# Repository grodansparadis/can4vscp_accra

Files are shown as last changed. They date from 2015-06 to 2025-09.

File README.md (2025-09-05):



-----

# The CAN4VSCP Accra general counter module</h1>

This module is part of the [VSCP project](https://www.vscp.org).  It is free to use, modify and sell. The only thing we kindly ask is that improvements and extensions are contributed back to the project (at your will). This to make the project better for everyone. All design files is licensed under the [MIT license](https://en.wikipedia.org/wiki/MIT_License).

The module is documented [here](https://grodansparadis.github.io/can4vscp_accra/#/)

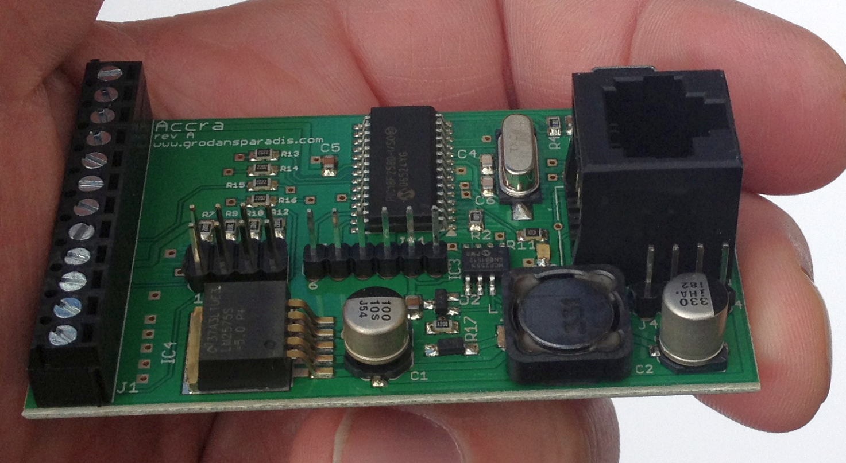
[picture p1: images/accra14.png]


## Abstract

Accra is a general counter module that connects to a CAN4VSCP bus and can count pulses on four channels. The module can be attached to a standard DIN Rail or be mounted directly on a wall.

The module fully adopts to the CAN4VSCP specification and can be powered directly over the bus with a 9-28V DC power source. It has a rich register set for configuration and any information events defined. It also have a decision matrix for easy dynamic event handling.

VSCP CAN modules are designed to work on a VSCP4CAN bus which use ordinary RJ-45 connectors and is powered with 9-30V DC over the same cable. This means there is no need for a separate power cable. All that is needed is a CAT5 or better twisted pair cable. Bus length can be a maximum of 500 meters with drops of maximum 24 meters length (up to a total of 120 meters). As for all VSCP4CAN modules the communication speed is fixed at 125 kbps.

All VSCP modules contains information of there own setup, manual, hardware version, manufacturer etc. You just ask the module for the information you need and you will get it. When they are started up they have a default functionality that often is all that is needed to get a working setup. If the module have something to report it will send you an event and if it is setup to react on a certain type of event it will do it's work when you send event(s) to it. 

---

## Project files

### User manual
  * [User Manual](https://grodansparadis.github.io/can4vscp_accra/#)

### Schematic, PCB, 3D files etc
  * [Schematics reversion A](https://raw.githubusercontent.com/grodansparadis/can4vscp_accra/refs/heads/master/eagle/accra_sch_rev_A.png)
 * Hardware design files is made in [KiCad](https://kicad.org) and can be found in the `kicad` directory. Valid from reversion B of the hardware.
   * Gerber files for PCB production can be found in the `gerber` directory (in the `kicad` folder).
 * Eagle schema and board files for reversion A and B can be found in the `eagle` directory. They are no longer actively updated.

 ### Firmware

 The firmware is developed in [MPLAB X IDE](https://www.microchip.com/mplab/mplab-x-ide) using the [XC8 compiler](https://www.microchip.com/mplab/compilers).

  * Binary release files is available [here](https://github.com/grodansparadis/can4vscp_kelvin_ntc10k/releases)

### MDF - Module Description File(s)
  * [MDF file version: 6 Release date: 2024-04-22](http://www.eurosource.se/accra_1.xml)

### Support
If you need support, please open an issue in the [GitHub repository](https://github.com/grodansparadis/can4vscp_kelvin_ntc10k/issues).

### Buy a ready made modules
You can buy a ready made module from [Grodans Paradis](http://www.grodansparadis.com).

### Project related links
  * [VSCP project](https://www.vscp.org)
  * [VSCP Documentation site](https://docs.vscp.org/)
  * [VSCP Wiki](https://github.com/grodansparadis/vscp/wiki)

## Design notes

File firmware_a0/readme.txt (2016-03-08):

Readme file for the Kelvin SHT11 project. This project is also the base for a VSCP implemention
on a Microchip 18F PIC device.

Version 0.03 2004-12-24

This project ia available in two versions for each processor. One have an "i" at the end meaning that it 
is for the ICD2 debugger.

Non ICD2 projects are built for use with the bootloader. The bootloader occupies space between 0x000 and 0x1ff. 
Vectors are relocated to 0x200. This is managed in the linker scripts. Also the C initialization code has 
been changed to start code at the relocated vector. This also means that the bootloader has to be programmed
into the chip before the working with the project. It also means that the environment must be configured 
*not* to erase the chip before programming it.

If no bootloader is required it is OK to use the standard C startup code, a standard linker description. In this 
case the absolute vector address for the low priority interrup in main.c  must be changed back froo 0x218 to 0x18.

Steps you should go through to adopt this file for your own VSCP project.
=========================================================================

1.) The frequency for your system may be different. This will affect the CAN bit rate settings
which are defined in the biginning of the can18f.c file. Here you also find the filter/mask 
defines if you need to change these.

Timer0 is used as a 1 ms timer for the VSCP functionality. You should adopt the timer reload value 
in the main.h file to your system.

2.) The GUID (Glocal Unique ID) is defined in the beginning of vscp.c This number should be 
different for each piece of equiment you produce. Regard it is as the device serial number. It
can be moved to EEPROM if that is found more convinient. In that case the vscp_rcv_readreg 
procedure in vscp.c also has to be changed.

3.) The device URL is defined in the beginning of the vscp.c file. This is an URL without the
initial "http://" that should point to a XML file that give information about your piece of 
equipment.

4.) The manufacturer id is also defined in the beginning of the vscp.c file. You can use this
id in any way you like.

In addition to this you may use different pins for the INIT button (RC0 today) and the 
status LED (RC1) today. Changes affect the main interrupt vector.

Available builds
================
- kelvin_sht_458i.mcw is for a special 18F485 board *with* ICD2 support.
- kelvin_sht_458.mcw is for 18F485 board *with* bootloader.
- kelvin_sht_258i.mcw is for tke Levin board *with* ICD2 support.
- kelvin_sht_258.mcw is for tke Levin board *with* bootloader.

VSCP (Very Simple Control Protocol) 
http://www.vscp.org

akhe@eurosource.se

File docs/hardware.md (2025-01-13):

## Most current information

You can find the most current information about the Accra module at it's repsitory <https://github.com/grodansparadis/can4vscp_accra> and in the documentation at 
<https://grodansparadis.github.io/can4vscp_accra>. In the repository you can
also find links to the latest firmware, drivers and schematics etc for
its use. You can find links to where you can buy ready made modules here.

## The raw facts

| Parameter | Value |
| --- | --- |
| Current hardware reversion | A |
| Current firmware version | 1.0.0 |
| Supply voltage | \+9 - +28 VDC |
| PCB Size | 42mm x 72mm |
| Power requirements | 0.1W |
| Communication: CAN4VSCP (CAN) | 125 kbps |
| Max frequency channel 0/1 | 25KHz |
| Max frequency channel 2/3 | 10KHz |

## Schematics

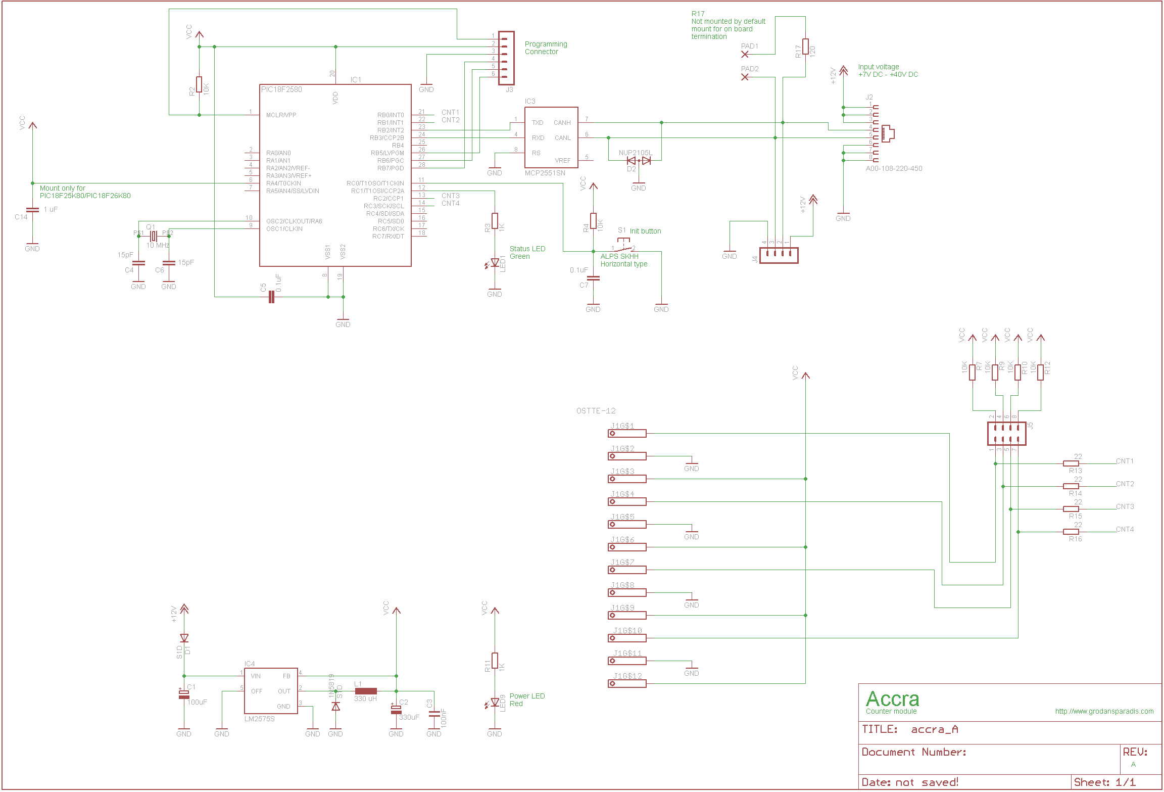
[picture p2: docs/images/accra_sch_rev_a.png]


Schematics: Rev A (click picture to enlarge)

## Board components

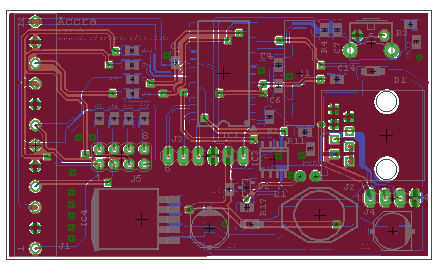
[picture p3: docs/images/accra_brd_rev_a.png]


## Connectors

### Terminal block

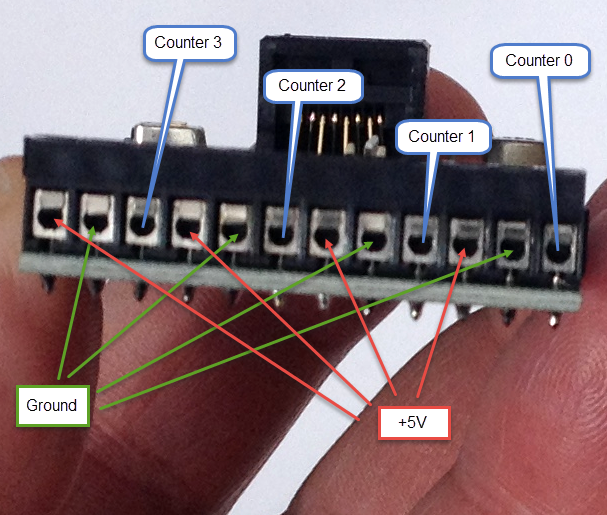
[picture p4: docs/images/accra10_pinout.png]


| Pin | Description |
| --- | --- |
| 1 | Counter 0 input |
| 2 | GND |
| 3 | \+5V |
| 4 | Counter 1 input |
| 5 | GND |
| 6 | \+5V |
| 7 | Counter 2 input |
| 8 | GND |
| 9 | \+5V |
| 10  | Counter 3 input |
| 11  | GND |
| 12  | \+5V |

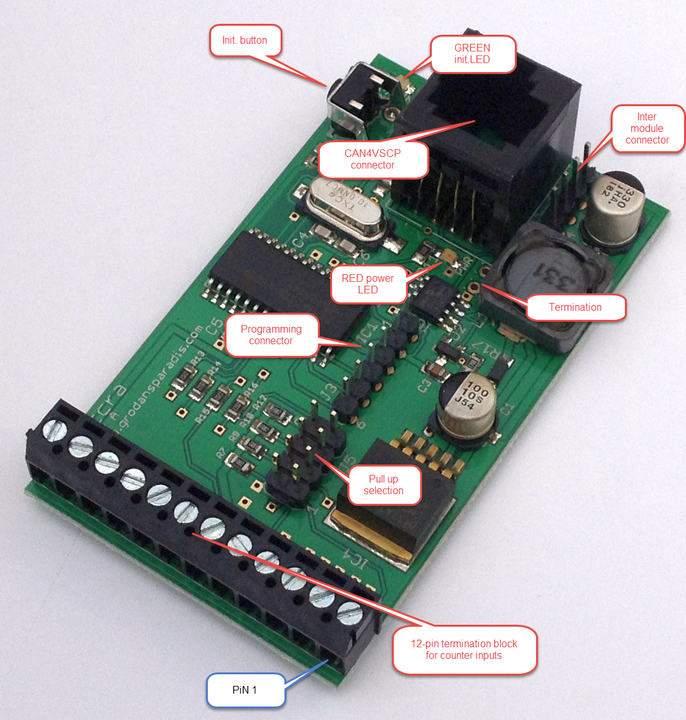
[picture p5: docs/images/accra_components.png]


### Pull up's

| pair | Description |
| ---- | --- |
| 1-2  | Enable 10K pullup to 5V for channel 0 |
| 3-4  | Enable 10K pullup to 5V for channel 1 |
| 5-6  | Enable 10K pullup to 5V for channel 2 |
| 7-0  | Enable 10K pullup to 5V for channel 3 |

### RJ-XX pin-out

The unit is powered over the CAN4VSCP bus. The CAN4VSCP normally uses
CAT5 or better twisted pair cable. You can use other cables if you
which. The important thing is that the CANH and CANL signals uses a
twisted cable. For connectors you can use RJ10, RJ11, RJ12 or the most
common RJ45 connectors.

Recommended connector is RJ-34/RJ-12 or RJ-11 with pin out as in this
table.

| Pin | Use | RJ-11 | RJ-12 | RJ-45 | Patch Cable wire color T568B |
| ----- | --- | ----- | ----- | ----- | --- |
| 1 | \+9-28V DC | | | RJ-45 | Orange/White |
| 2 1 | \+9-28V DC | | RJ-12 | RJ-45 | Orange |
| 3 2 1 | \+9-28V DC | RJ-11 | RJ-12 | RJ-45 | Green/White |
| 4 3 2 | CANH | RJ-11 | RJ-12 | RJ-45 | Blue |
| 5 4 3 | CANL | RJ-11 | RJ-12 | RJ-45 | Blue/White |
| 6 5 4 | GND | RJ-11 | RJ-12 | RJ-45 | Green |
| 7 6 | GND | | RJ-12 | RJ-45 | Brown/White |
| 8 | GND | | | RJ-45 | Brown |

---

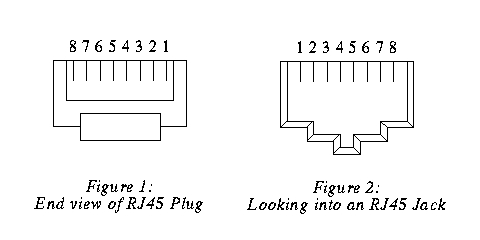
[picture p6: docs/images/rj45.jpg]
RJ-11/12/45 pin-out
 

**RJ-11/12/45 pin-out**

:\!: Always use a pair of twisted wires for CANH/CANL for best noise
immunity. If the EIA/TIA 56B standard is used this condition will be
satisfied. This is good as most Ethernet networks already is wired this
way.

### Inter module connector

The inter module connector can be used to connect modules that are
physically close to each other together in an easy way. Remember that
the minimum length of a connection cable is 30 cm.

| Pin | Description |
| --- | --- |
| 1 | Power from CAN4VSCP bus |
| 2 | CANH |
| 3 | CANL |
| 4 | GND |



### PIC programming Connector

| pin | Description |
| --- | --- |
| 1 | Reset |
| 2 | VCC |
| 3 | GND |
| 4 | PGD (RX of second serial port is here to) |
| 5 | PGC (TX of second serial port is here to) |
| 6 | LWPGM |



### Functionality of the status LED

The LED is used to indicate the status of the module. It will light
steady when the firmware is running and will blink when the module is in
the nickname discovery process.

| LED | Description  |
| --- | --- |
| Steady | No error. Firmware running. |
| Blinking | Module is going through the [nickname discovery process](http://www.vscp.org/docs/vscpspec/doku.php?id=vscp_level_i_specifics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). |

### CAN

CAN4VSCP is a CAN based bus running at 125 kbps with the addition of DC
power. If you are interested in how CAN works you have a pretty good
intro [here](http://www.eeherald.com/section/design-guide/esmod9.html).

CAN is known to be robust and is there for used in vehicles and in the
industry.

[filename](./bottom-copyright.md ':include')

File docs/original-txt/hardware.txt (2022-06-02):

====== Hardware ======

=====  Most current information ===== 
You can find the most current information about the Accra module at \\ [[http://www.grodansparadis.com/accra/accra.html]]. On the site you can also find links to the latest firmware, drivers and schematics etc for its use. 

=====  The raw facts ===== 

^ Parameter ^ Value ^
| Current hardware reversion | A |
| Current firmware version | 1.0.0 |
| Supply voltage | +9 - +28 VDC |
| PCB Size | 42mm x 72mm |
| Power requirements | 0.1W |
| Communication: CAN4VSCP (CAN) | 125 kbps |
| Max frequency channel 0/1 | 25KHz |
| Max frequency channel 2/3 | 10KHz |

===== Schematics ===== 

{{:accra_sch_rev_a.png?700|}}

Schematics: Rev A (click picture to enlarge)

===== Board components ===== 

{{:accra_components.png?700|}}
===== Connectors =====

==== Terminal block ====

{{:accra10_pinout.png?400|}}

^ Pin ^ Description ^ 
| 1 | Counter 0 input | 
| 2 | GND | 
| 3 | +5V | 
| 4 | Counter 1 input | 
| 5 | GND | 
| 6 | +5V | 
| 7 | Counter 2 input | 
| 8 | GND | 
| 9 | +5V | 
| 10 | Counter 3 input | 
| 11 | GND | 
| 12 | +5V | 

==== Pull up's ====

^ pair ^Description ^
| 1-2 | Enable 10K pullup to 5V for channel 0 |
| 3-4 | Enable 10K pullup to 5V for channel 1 |
| 5-6 | Enable 10K pullup to 5V for channel 2 |
| 7-0 | Enable 10K pullup to 5V for channel 3 |

==== RJ-XX pin-out ====

The unit is powered over the CAN4VSCP bus. The CAN4VSCP normally uses CAT5 or better twisted pair cable. You can use other cables if you which. The important thing is that the CANH and CANL signals uses a twisted cable. For connectors you can use RJ10, RJ11, RJ12 or the most common RJ45 connectors.

Recommended connector is RJ-34/RJ-12 or RJ-11 with pin out as in this table.

^ Pin ^ Use ^ RJ-11 ^ RJ-12 ^ RJ-45 ^ Patch Cable wire color T568B ^
| 1 | +9-28V DC	| | | RJ-45 | Orange/White |
| 2 1 | +9-28V DC | | RJ-12 | RJ-45 | Orange |
| 3 2 1	| +9-28V DC | RJ-11 | RJ-12 | RJ-45 | Green/White |
| 4 3 2	| CANH | RJ-11 | RJ-12 | RJ-45 | Blue |
| 5 4 3	| CANL | RJ-11 | RJ-12 | RJ-45 | Blue/White |
| 6 5 4	| GND | RJ-11 | RJ-12 | RJ-45 | Green |
| 7 6 | GND | | RJ-12 | RJ-45 | Brown/White |
| 8 | GND |  |  | RJ-45 | Brown |

{{ :rj45.jpg?300 |RJ-11/12/45 pin-out}}
**RJ-11/12/45 pin-out**

:!: Always use a pair of twisted wires for CANH/CANL for best noise immunity. If the EIA/TIA 56B standard is used this condition will be satisfied. This is good as most Ethernet networks already is wired this way. 

==== Inter module connector ====

The inter module connector can be used to connect modules that are physically close to each other together in an easy way. Remember that the minimum length of a connection cable is 30 cm.

^ Pin ^Description ^
| 1 | Power from CAN4VSCP bus |
| 2 | CANH |
| 3 | CANL |
| 4 | GND |

\\ 

{{ :odessa_inter_module_connector.png?600 |}} 

==== PIC programming Connector ====

^ pin  ^ Description  ^
| 1 | Reset |
| 2 | VCC |
| 3 | GND |
| 4 | PGD (RX of second serial port is here to) |
| 5 | PGC (TX of second serial port is here to) |
| 6 | LWPGM |

\\ 

{{::odessa_programming_connector.png?700|}}

==== Functionality of the status LED ====

The LED is used to indicate the status of the module. It will light steady when the firmware is running and will blink when the module is in the nickname discovery process.

^ LED ^ Description ^
| Steady | No error. Firmware running. |
| Blinking | Module is going through the [[http://www.vscp.org/docs/vscpspec/doku.php?id=vscp_level_i_specifics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|nickname discovery process]]. |

==== CAN ====

CAN4VSCP is a CAN based bus running at 125 kbps with the addition of DC power. If you are interested in how CAN works you have a pretty good intro [[http://www.eeherald.com/section/design-guide/esmod9.html|here]].

CAN is known to be robust and is there for used in vehicles and in the industry.

\\ 
---- 
{{ :grodan_logo.png?100 |}}
\\ 
<html><center></html>
**Paradise of the Frog AB** Brattbergavägen 17 820 50 LOS SWEDEN\\  
**email:** [[info@grodansparadis.com]] **phone:** +46 (0)8 40011835 \\ 
**web:**[[http://www.grodansparadis.com]] \\ 
<html></center></html>

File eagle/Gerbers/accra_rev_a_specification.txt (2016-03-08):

Ake Hedman
Grodans Paradis AB

Date:				2014-06-18
Part Number: 		Accra
Number of cards:	120
Number of layers: 	2 
Material: 			FR4
Final Thickness:	1.6 mm
Final copper:		1/1oz
Surface treatment: 	ENIG
Unit Size:			72 x 42 mm
Panel Size:			154*126 mm
Unit/panel:			6
Solder Mask:		Green
Silk Screen: 		White	
Outline Profile:	CNC Routing + V-cut
X-out Allowed:		1
Stencil needed:		yes
Gerber layer for Stencil: Component Cream (pmc)

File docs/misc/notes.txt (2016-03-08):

Accra notes
===========

http://www.best-microcontroller-projects.com/pic-frequency-counter.html
http://www.best-microcontroller-projects.com/frequency-counter.html
http://www.circuitvalley.com/2011/07/60-mhz-frequency-meter-counter.html

Registers
=========
00	Zone
01	Subzone
02	Control register Counter 0
		Bit 0 - Enable
		Bit 1 - 
		Bit 2 - 
		Bit 3 - 
		Bit 4 - 
		Bit 5 - 
		Bit 6 -
		Bit 7 -  		
03	Control register Counter 1
04	Control register Counter 2
05	Control register Counter 3
06	Control register Counter 4

07	Counter 0 MSB
08	Counter 0 
09	Counter 0 
0A	Counter 0 LSB

0B	Counter 1 MSB
0C	Counter 1 
0D	Counter 1 
0E	Counter 1 LSB

0F	Counter 2 MSB
10	Counter 2 
11	Counter 2 
12	Counter 2 LSB

13	Counter 3 MSB
14	Counter 3 
15	Counter 3 
16	Counter 3 LSB

17	Counter 4 MSB
18	Counter 4 
19	Counter 4 
1A	Counter 4 LSB

1B  Delta channel 0 MSB
1C  Delta channel 0 LSB

1B  Frequency channel 0 MSB
1C  Frequency channel 0 
1D  Frequency channel 0 
1E  Frequency channel 0 LSB

1B  Frequency channel 1 MSB
1C  Frequency channel 1 
1D  Frequency channel 1 
1E  Frequency channel 1 LSB

1B  Frequency channel 2 MSB
1C  Frequency channel 2 
1D  Frequency channel 2 
1E  Frequency channel 2 LSB

1B  Frequency channel 3 MSB
1C  Frequency channel 3 
1D  Frequency channel 3 
1E  Frequency channel 3 LSB

1B  Frequency channel 4 MSB
1C  Frequency channel 4 
1D  Frequency channel 4 
1E  Frequency channel 4 LSB

// y = k*x + m
1F	Linear equation k constant double for channel 0 MSB
20	Linear equation k constant double for channel 0 
21	Linear equation k constant double for channel 0 
22	Linear equation k constant double for channel 0 MSB

23	Linear equation k constant double for channel 1 MSB
24	Linear equation k constant double for channel 1 
25	Linear equation k constant double for channel 1 
26	Linear equation k constant double for channel 1 MSB

27	Linear equation k constant double for channel 2 MSB
28	Linear equation k constant double for channel 2 
29	Linear equation k constant double for channel 2 
2A	Linear equation k constant double for channel 2 MSB

2B	Linear equation k constant double for channel 3 MSB
2C	Linear equation k constant double for channel 3 
2D	Linear equation k constant double for channel 3 
2E	Linear equation k constant double for channel 3 MSB

2F	Linear equation k constant double for channel 4 MSB
30	Linear equation k constant double for channel 4 
31	Linear equation k constant double for channel 4 
32	Linear equation k constant double for channel 4 MSB

33	Linear equation m constant double for channel 0 MSB
34	Linear equation m constant double for channel 0 
35	Linear equation m constant double for channel 0 
36	Linear equation m constant double for channel 0 MSB

37	Linear equation m constant double for channel 1 MSB
38	Linear equation m constant double for channel 1 
39	Linear equation m constant double for channel 1 
3A	Linear equation m constant double for channel 1 MSB

3B	Linear equation m constant double for channel 2 MSB
3C	Linear equation m constant double for channel 2 
3D	Linear equation m constant double for channel 2 
3E	Linear equation m constant double for channel 2 MSB

3F	Linear equation m constant double for channel 3 MSB
40	Linear equation m constant double for channel 3 
41	Linear equation m constant double for channel 3 
42	Linear equation m constant double for channel 3 MSB

43	Linear equation m constant double for channel 4 MSB
44	Linear equation m constant double for channel 4 
45	Linear equation m constant double for channel 4 
46	Linear equation m constant double for channel 4 MSB

1:00	Control for measurement event sensor 0
		Bit 0 - Event selection
		Bit 1 - Event selection
		Bit 2 - Event selection
		Bit 3 - 
		Bit 4 - 
		Bit 5 - 
		Bit 6 -
		Bit 7 - 
		
1:01	Control for measurement event sensor 1		
1:02	Control for measurement event sensor 2
1:03	Control for measurement event sensor 3
1:04	Control for measurement event sensor 4

1:05  	Zone for measurement event sensor 0
1:06  	Zone for measurement event sensor 1
1:07  	Zone for measurement event sensor 2
1:08  	Zone for measurement event sensor 3
1:09  	Zone for measurement event sensor 4

1:0A  	Subzone for measurement event sensor 0
1:0B  	Subzone for measurement event sensor 1
1:0C  	Subzone for measurement event sensor 2
1:0D  	Subzone for measurement event sensor 3
1:0E  	Subzone for measurement event sensor 4

1:0F  	Event class for measurement event sensor 0 MSB
1:10  	Event class for measurement event sensor 0 LSB

1:11  	Event class for measurement event sensor 0 MSB
1:12  	Event class for measurement event sensor 0 LSB

1:13  	Event class for measurement event sensor 0 MSB
1:14  	Event class for measurement event sensor 0 LSB

1:15  	Event class for measurement event sensor 0 MSB
1:16  	Event class for measurement event sensor 0 LSB

1:17 	Event class for measurement event sensor 0 MSB
1:18  	Event class for measurement event sensor 0 LSB

1:19  	Event type for measurement event sensor 0 MSB
1:1A  	Event type for measurement event sensor 0 LSB

1:1B	Data coding for measurement event sensor 0
1:1C	Data coding for measurement event sensor 1
1:1D	Data coding for measurement event sensor 2
1:1E	Data coding for measurement event sensor 3
1:1F	Data coding for measurement event sensor 4

Actions
=======
0	NOOP
1	Send state. (for sync)

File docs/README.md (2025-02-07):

## Manual for the Accra module

**Document version:** ${/var/document-version} - ${/var/creation-time}
[HISTORY](./history.md)

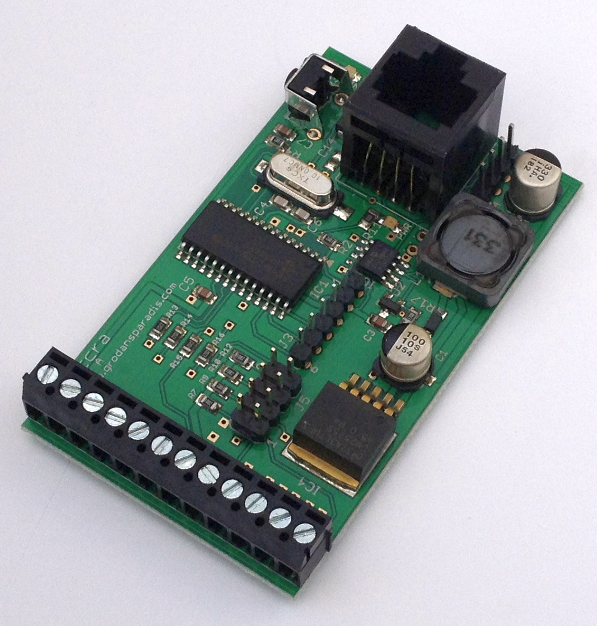
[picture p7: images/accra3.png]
Accra


Accra is a module that have four counter channels that each can count
pulses and measure frequency. Each channel can have alarms set for going
over a counter level or when counting down to zero and for a frequency
that goes outside of a specified frequency window.

It has a built-in linear calculation algorithm that can translate pulse
to real world measurement units. This can for example be used for
utility meter measurements and gives the correct measurement value sent
out on the VSCP bus.

The module comes with a GUID and is programmed with a bootloader and
VSCP module functionality that works right out of the box.

* [Repository for the module](https://github.com/grodansparadis/can4vscp_accra)
  * This manual is available [here](https://grodansparadis.github.io/can4vscp_accra/)
  * Latest schema for the module is available [here](https://github.com/grodansparadis/can4vscp_accra/tree/master/eagle)
  * Latest firmware for the module is available [here](https://github.com/grodansparadis/can4vscp_accra/tree/master/firmware)
  * [MDF for the module](https://github.com/grodansparadis/can4vscp_accra/tree/master/mdf)

## VSCP

VSCP logo

VSCP is a free and open automation protocol for IoT and m2m devices. Visit [the VSCP site](https://www.vscp.org) for more information.

**VSCP is free.** Placed in the **public domain**. Free to use. Free to change. Free to do whatever you want to do with it. VSCP is not owned by anyone. VSCP will stay free and gratis forever.

The specification for the VSCP protocol is [here](https://docs.vscp.org) 

VSCP documentation for various parts can be found [here](https://docs.vscp.org/).

If you use VSCP please consider contributing resources or time to the project ([https://vscp.org/support.php](https://vscp.org/support.php)).

## Buy a module

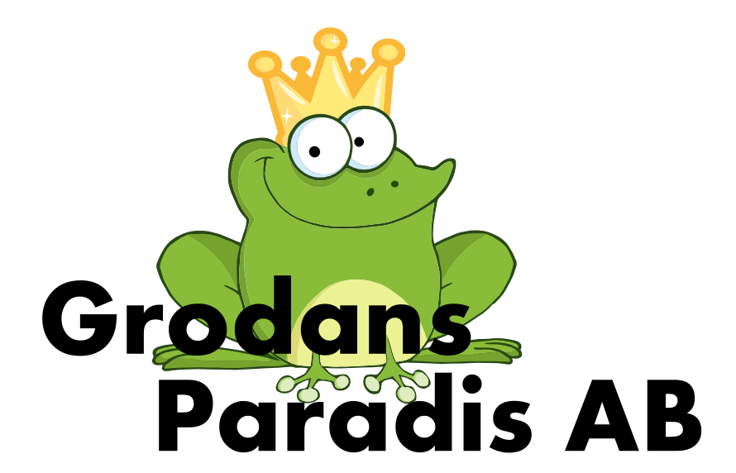
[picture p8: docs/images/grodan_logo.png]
Grodans PAradis AB


Ready made modules can be bought from [Grodans Paradis AB](https://www.grodansparadis.com).

## Document license

This document is licensed under [Creative Commons BY 4.0](https://creativecommons.org/licenses/by/4.0/) and can be freely copied, redistributed, remixed, transformed, built upon as long as you give credits to the author.

[filename](./bottom-copyright.md ':include')

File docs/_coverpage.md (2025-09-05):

VSCP logo

# Manual for the Accra module

Scroll down to view docs.

[Homepage](https://www.vscp.org)
[Docs](https://www.vscp.org/#documentation)
[Downloads](https://www.vscp.org/#download)
[Get Started](./README)

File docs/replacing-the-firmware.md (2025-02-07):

New firmware is released from time to time for all our modules. We
expect this to be true also for the module as it is an active
project. The process of updating the firmware of the module is a simple
one. Just follow the steps outlined in the [VSCP Works
documentation](https://grodansparadis.github.io/vscp-works-qt/#/bootload_window).

## Where is the firmware?

Firmware is available in the Github repository
<https://github.com/grodansparadis/can4vscp_accra/releases> and the [MDF of the module](https://github.com/grodansparadis/can4vscp_accra/tree/master/mdf) contains a list of available firmware files and a pointer to there location. This file is loaded by the firmware updating software of VSCP Works+ and you can select the file you need from there.

### Device firmware code
The standard registers of a module contains a register that holds the firmware code for the module. This is a 16-bit value that can be read by the VSCP firmware update software. The value is a code for the specific hardware the board uses. Typically hardware has been changed and processors have been updated to later versions as time goes. The VSCP firmware update software can use this code to find the correct firmware for the module. It is **VERY** important that the correct firmware is used for the module. If the wrong firmware is used the module will not work as expected and may even be damaged. So make sure this code is the same as the code in the firmware file you use.

Older firmware files may not have this code in the standard registers as it is a pretty late addition to the standard. In that case you should use the latest firmware file for the module for the type of processor you have.

## Where is the source for the firmware?

You can find the latest source for the firmware
[here](https://github.com/grodansparadis/can4vscp_frankfurt_rs232).

## Replacing/updating the bootloader on the module

If you need to update the bootloader on this module you can find firmware files for it [here](https://github.com/grodansparadis/vscp-pic1-bootloader/releases). Select the hex files for your board and use the bootloader application to update the bootloader. When the bootloader is loaded you can use [VSCP Works+](https://grodansparadis.github.io/vscp-works-qt/#/bootload_window) to update the application firmware of the module.

You will need a PICkit3 or similar programmer to update the bootloader.

[filename](./bottom-copyright.md ':include')

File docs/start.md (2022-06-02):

# Accra - General counter module

**Document reversion**: 1.0.0 2015-07-07

Copyright © 2000-2020 Åke Hedman, [Grodans Paradis
AB](http://www.grodansparadis.com),
\<[akhe@grodansparadis.com](akhe@grodansparadis.com)\>

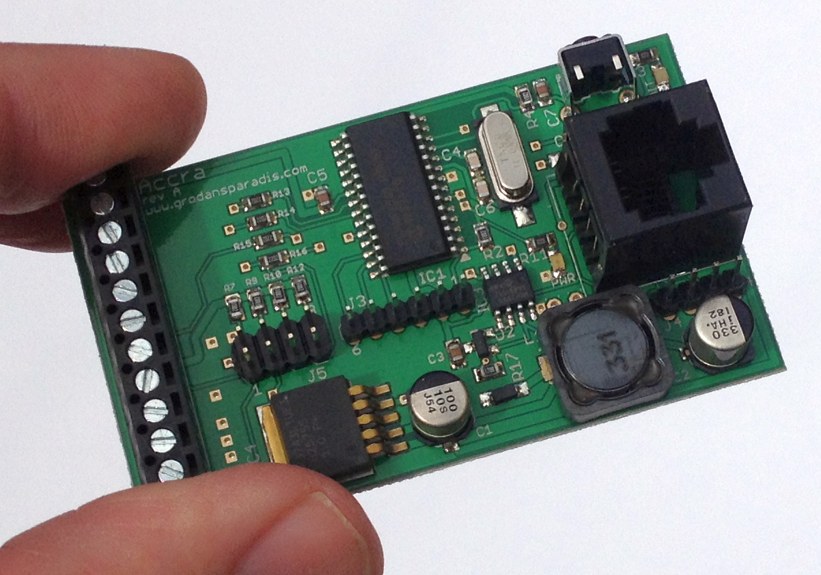
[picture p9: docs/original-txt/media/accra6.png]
Accra


This documentation is for the [Accra
module](http://www.grodansparadis.com/accra/accra.html). The module is
available for international purchase from the
[FrogShop](http://www.frogshop.se).

  - [Introduction](Introduction)
  - [Getting Started](Getting%20Started)
  - [Hardware](Hardware)
  - [CAN4VSCP cabling](CAN4VSCP%20cabling)
  - [Updating the firmware](Replacing%20the%20firmware)
  - [Registers](registers)
  - [Abstractions](Abstractions)
  - [Alarms](Alarms)
  - [Decision Matrix](decisionmatrix)
  - [Events](Events)
  - [Recipes](Recipes)
  - [faq](faq)

//**Disclaimer:** © 2011-2015 Grodans Paradis AB. All rights reserved.
Grodans Paradis AB®, logo and combinations thereof, are registered
trademarks of Grodans Paradis AB. Other terms and product names may be
trademarks of others. The information in this document is provided in
connection with Grodans Paradis AB products. No license, express or
implied or otherwise, to any intellectual property right is granted by
this document or in connection with the sale of Grodans Paradis AB
products. Neither the whole nor any part of the information contained in
or the product described in this document may be adapted or reproduced
in any material from except with the prior written permission of the
copyright holder. The product described in this document is subject to
continuous development and improvements. All particulars of the product
and its use contained in this document are given by Grodans Paradis AB
in good faith. However all warranties implied or expressed including but
not limited to implied warranties of merchantability or fitness for
purpose are excluded. This document is intended only to assist the
reader in the use of the product. Grodans Paradis AB. shall not be
liable for any loss or damage arising from the use of any information in
this document or any error or omission in such information or any
incorrect use of the product. //

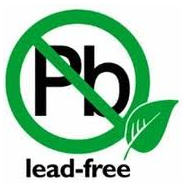
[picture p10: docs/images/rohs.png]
 All boards produced by Grodans Paradis AB are ROHS
compliant.

\----   
<center> **Grodans Paradis AB** Brattbergavägen 17, 827 70 LOS SWEDEN  
**email:** [info@grodansparadis.com](info@grodansparadis.com) **phone:**
+46 (0)8 40011835  
**web:**<https://www.grodansparadis.com>  
</center>

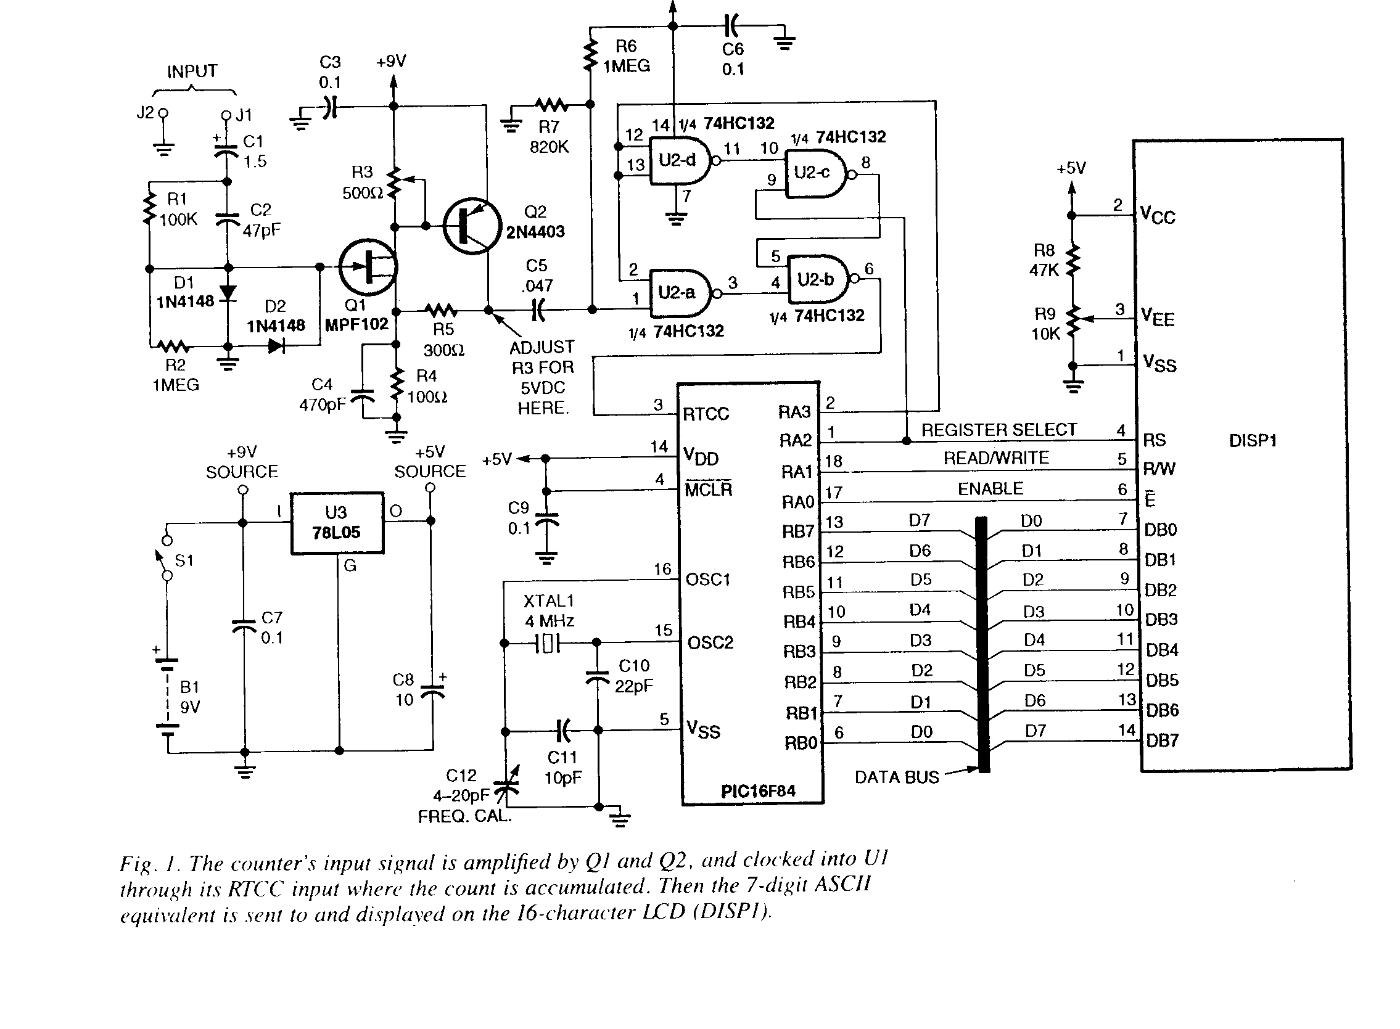
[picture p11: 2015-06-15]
docs/misc/weedfreq.gif

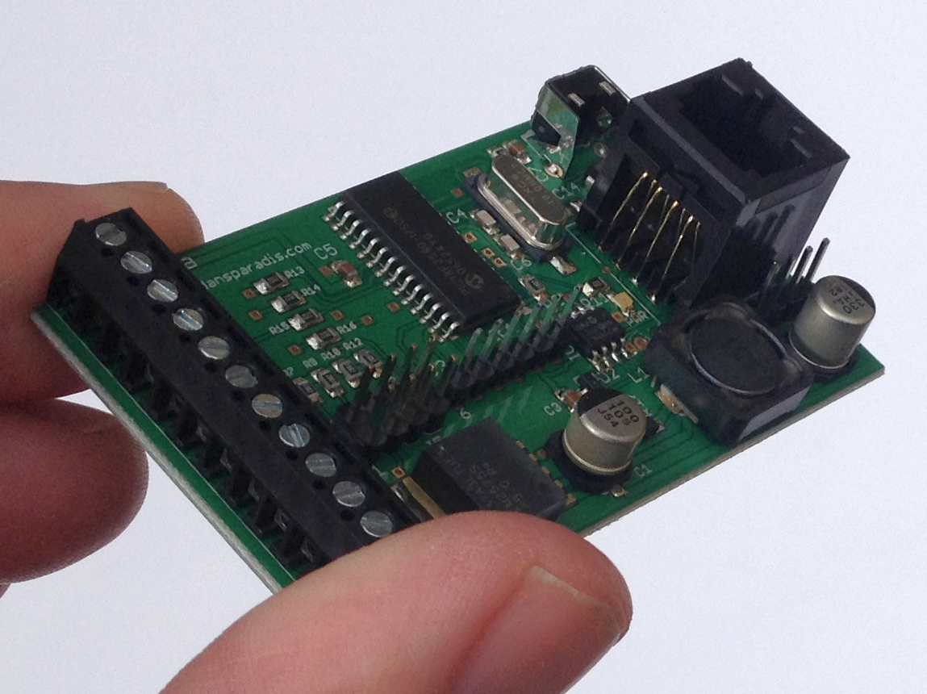
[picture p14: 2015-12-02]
docs/images/accra7.png

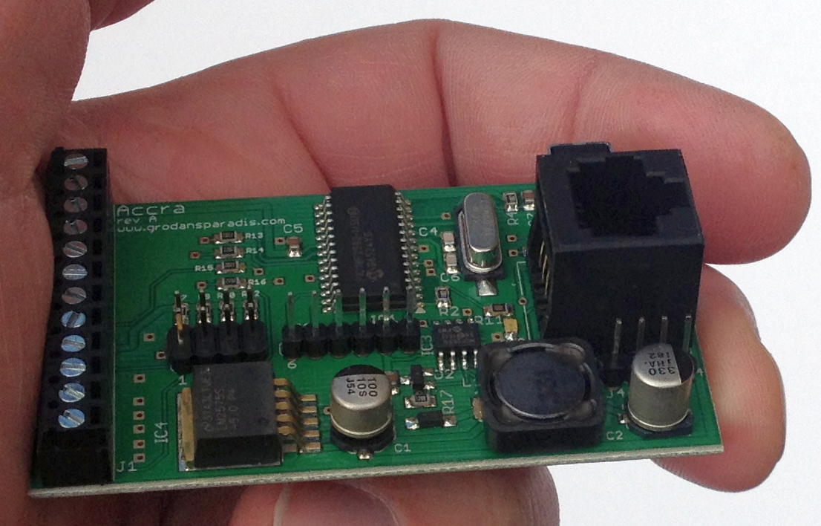
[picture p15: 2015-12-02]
docs/original-txt/media/accra15.png

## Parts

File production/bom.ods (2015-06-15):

Count | Description | Part id | Supplier 1 | Partnumber 1 | Price 1 | Price 1000
1 | Brytare ALPS SKHH Horizontal | S1 | Elfa | 35-677-65 | SEK 2,89 | SEK 1,49
1 | Stiftlist 2.54 6-pin | JP1,JP4 | Digikey | SAM1035-50-ND | USD 2.04 | USD 1.01
1 | Induktance 330 uH, 1A, DO3316P | L1 | Digikey | 553-1514-1-ND | USD 1.28 | USD 1.05
1 | Crystal, SMD, 10 Mhz | Q1 | Digikey | 887-1050-1-ND | USD 0.53 | USD 0.26
1 | LED SMD yellow | LED1
2 | Capacitance 0.1uF 0805 | C3,C5 | Digikey | 311-1361-2-ND | USD 24/4000
1 | Resistance 1K 0805 | R3
1 | Capacitance 100uF | C1
1 | Capacitance 330uF | C2
1 | LM2575S | IC4 | Digikey | LM2575S-3.3/NOPB-ND | USD 2.97 | USD 1.48
1 | MCP2551 SOIC | IC3 | Digikey | MCP2551-I/SN-ND | USD 1.12 | USD 0.78
1 | Diod NUP2105L | D2 | Digikey | NUP2105LT1GOSCT-ND | USD 0.50 | USD 0.17
1 | Microprocessor PIC18F2580 | IC1 | Microchip direct | PIC18F2580-I/SO-ND | USD 5.51 | USD 5.24
1 | ULN2003AD | IC2 | Digikey | 296-1368-1-ND | USD 0.68 | USD 0.23
2 | Resistance 10K 0805 | R2,R4
2 | Capacitance 15pF 0805 | C4,C6 | Digikey | 709-1170-2-ND | USD28.80
2 | Diode 1N5819 SOD123 | D1 | Digikey | 1N5819HW-FDICT-ND | USD 0.48 | USD 0.10
1 | PCB |  | Pcbcart |  | USD 2.05 | USD 1.29
1 | Terminating block 10-pol |  | Digikey | ED2737-ND | USD 1.46 | USD 0.87
1 | RJ-45 connector | J2 | Digikey | 151-1099-ND | USD 0.70 | USD 0.49

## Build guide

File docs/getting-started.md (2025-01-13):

You need

  * RJ-45 patch cables or similar.
  * A stable +9V - +28V DC power source.
  * A host computer with a serial or USB interface.

The Accra module is powered from the CAN4VSCP bus. [This
article](https://github.com/grodansparadis/vscp/wiki/Connecting-CAN4VSCP-devices-together)
have information on how the bus is powered and set up. Follow it for a
reliable setup. Don't forget the 120 ohm terminators at each end of the
bus. <span class="underline">They are important\!</span> You can
activate the on board terminator on the Accra module if it is located at
one end of your bus.

When you power the module by inserting the RJ-45 cable the red LED on
the board should light up to indicate it is powered. This is just a
power indicator LED. When you power the board for the first time the
green led starts to blink to indicate that the module search for a
nickname. During normal operation this LED should light steady.

Remember that there need to be <span class="underline">at least
two</span> CAN4VSCP (or other CAN device set to 125kbps) devices (one
additional) if you have the [Frankfurt
RS-232](https://grodansparadis.github.io/can4vscp-frankfurt-rs232)
or some other bus interface. A single device can't talk by
itself on a bus. It's an error.

[filename](./bottom-copyright.md ':include')

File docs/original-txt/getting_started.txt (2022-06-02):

====== Getting started ======
 
You need

  * RJ-45 patch cables or similar.
  * A stable +9V - +28V DC power source.
  * A host computer with a serial or USB interface.

The Accra module is powered from the CAN4VSCP bus. [[http://www.grodansparadis.com/wiki/doku.php?id=connecting_can4vscp_devices_together|This article]] have information on how the bus is powered and set up. Follow it for a reliable setup. Don't forget the 120 ohm terminators at each end of the bus. __They are important!__  You can activate the on board terminator on the Accra module if it is located at one end of your bus.

When you power the module by inserting the RJ-45 cable the red LED on the board should light up to indicate it is powered. This is just a power indicator LED. When you power the board for the first time the green led starts to blink to indicate that the module search for a nickname. During normal operation this LED should light steady. 

Remember that there need to be __at least two__ CAN4VSCP (or other CAN device set to 125kbps) devices (one additional if you have the [[http://www.grodansparadis.com/frankfurt/rs232/frankfurt-rs232.html|Frankfurt RS-232]]) on the bus to be able to communicate. A single device can't talk by itself on a bus. It's an error.

\\ 
---- 
{{ :grodan_logo.png?100 |}}
\\ 
<html><center></html>
**Paradise of the Frog AB** Brattbergavägen 17 820 50 LOS SWEDEN\\  
**email:** [[info@grodansparadis.com]] **phone:** +46 (0)8 40011835 \\ 
**web:**[[http://www.grodansparadis.com]] \\ 
<html></center></html>

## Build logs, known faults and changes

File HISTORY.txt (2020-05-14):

Accra counter module
====================

2020-05-08 AKHE - Version is 1.0.4   Firmware 1.6.3
2020-05-14 AKHE - Fixed bug that cause init to be performed on all
                  cold starts. Fixed seconds timer.
2020-05-08 AKHE - Version is 1.0.3   firmware 1.6.3
2020-05-08 AKHE - Boot button time increased to > 2500 ms
2016-04-19 AKHE - RA4 set to input to prevent collision with VCAP circuits in 
                  PIC18F2580. Brown out raised to maximum (3V & 4.6V). Valable 
		  input from Anders Forsgren, AJE Electronics AB. 
2016-04-11 AKHE - vscp_getMatrixInfo nw use the pointer supplied by the framework.
2016-04-04 AKHE - Changed value of C14 to 10uF
2016-03-23 AKHE - Version 1.0.2-------------------------------------------------
2016-03-23 AKHE - Adopted for VSCP frimware 1.6.1
2016-03-23 AKHE - Version 1.0.1-------------------------------------------------
2016-03-23 AKHE - Adopted for VSCP firmware 1.6.0
2016-03-23 AKHE - Fixed bug in control byte write.
2016-03-08 AKHE - Adopted to 1.6 firmware. Adopted for PIC18F26K80.
2015-11-15 AKHE - Started development

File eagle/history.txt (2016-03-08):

Accra
=====

2014-06-19 - AKHE Fixed dimensions.
2014-06-18 - AKHE Job sent away.
2014-06-18 - AKHE Changed width on power wires.
2014-06-01 - AKHE Tested with Silvercircuits dru.

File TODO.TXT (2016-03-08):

Accra counter module
====================

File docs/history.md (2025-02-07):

# Change Log for Accra

Change log for the module is at
[here](https://github.com/grodansparadis/can4vscp_accra/blob/master/HISTORY.txt)

| Date | By | Description |
| ---- | -- | ---  |
| 250113 | akhe | Fixed some links |
| 220602 | akhe | Transferred to Markdown format |

[filename](./bottom-copyright.md ':include')

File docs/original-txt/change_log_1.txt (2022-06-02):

====== Change Log for Accra ======

Change log is [[https://github.com/grodansparadis/can4vscp_accra/blob/master/HISTORY.txt|here]]

\\ 
---- 
{{ :grodan_logo.png?100 |}}
\\ 
<html><center></html>
**Paradise of the Frog AB** Brattbergavägen 17 820 50 LOS SWEDEN\\  
**email:** [[info@grodansparadis.com]] **phone:** +46 (0)8 40011835 \\ 
**web:**[[http://www.grodansparadis.com]] \\ 
<html></center></html>

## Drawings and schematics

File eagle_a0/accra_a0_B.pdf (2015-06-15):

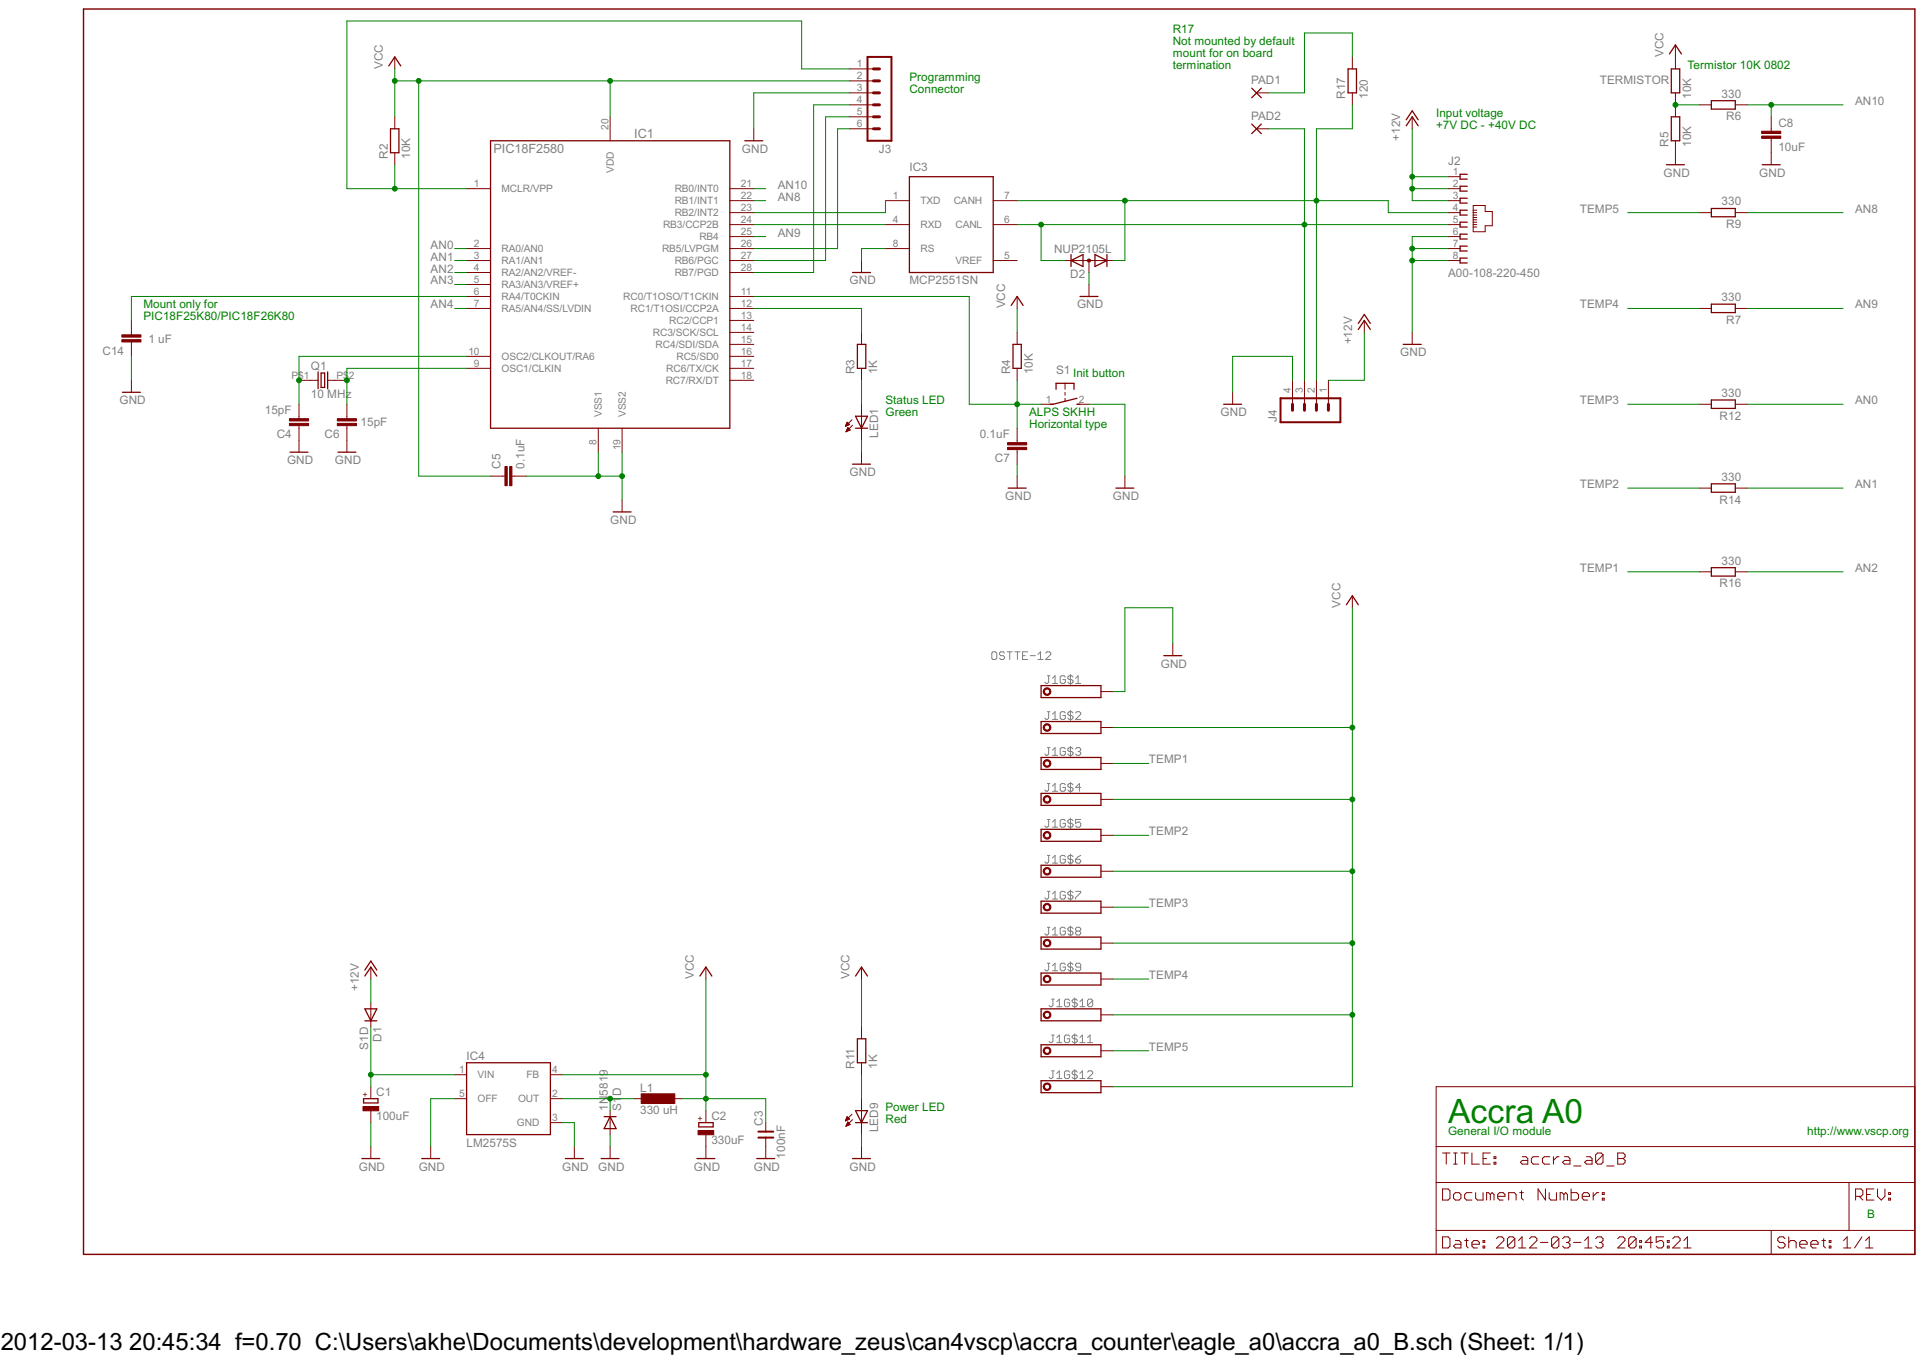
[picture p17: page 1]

termination R17
Not mounted by default mount for on board

Input voltage +7V DC - +40V DC

Init button Status LED

2012-03-13 20:45:34 f=0.70 C:\Users\akhe\Documents\development\hardware_zeus\can4vscp\accra_counter\eagle_a0\accra_a0_B.sch (Sheet: 1/1)

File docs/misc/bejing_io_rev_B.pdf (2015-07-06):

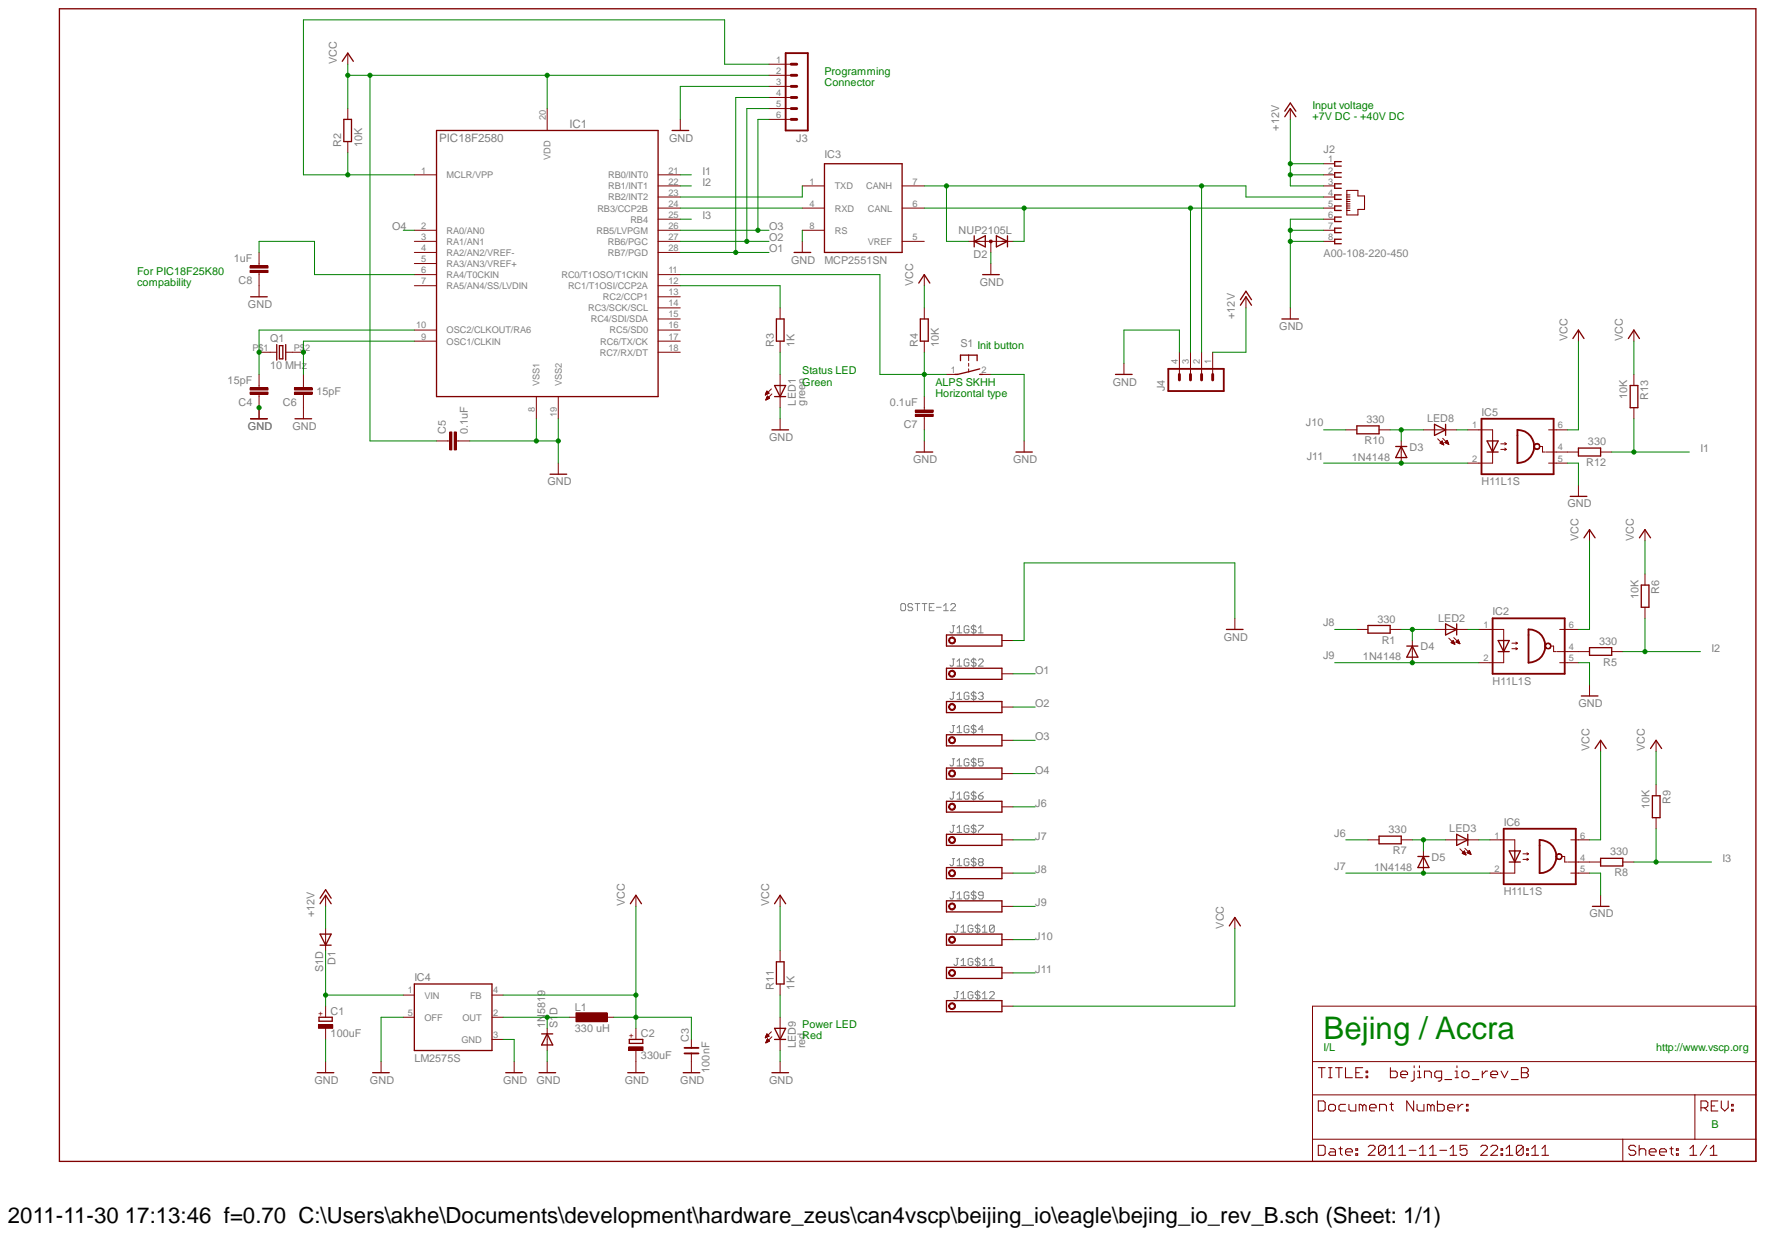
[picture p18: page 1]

2011-11-30 17:13:46 f=0.70 C:\Users\akhe\Documents\development\hardware_zeus\can4vscp\beijing_io\eagle\bejing_io_rev_B.sch (Sheet: 1/1)

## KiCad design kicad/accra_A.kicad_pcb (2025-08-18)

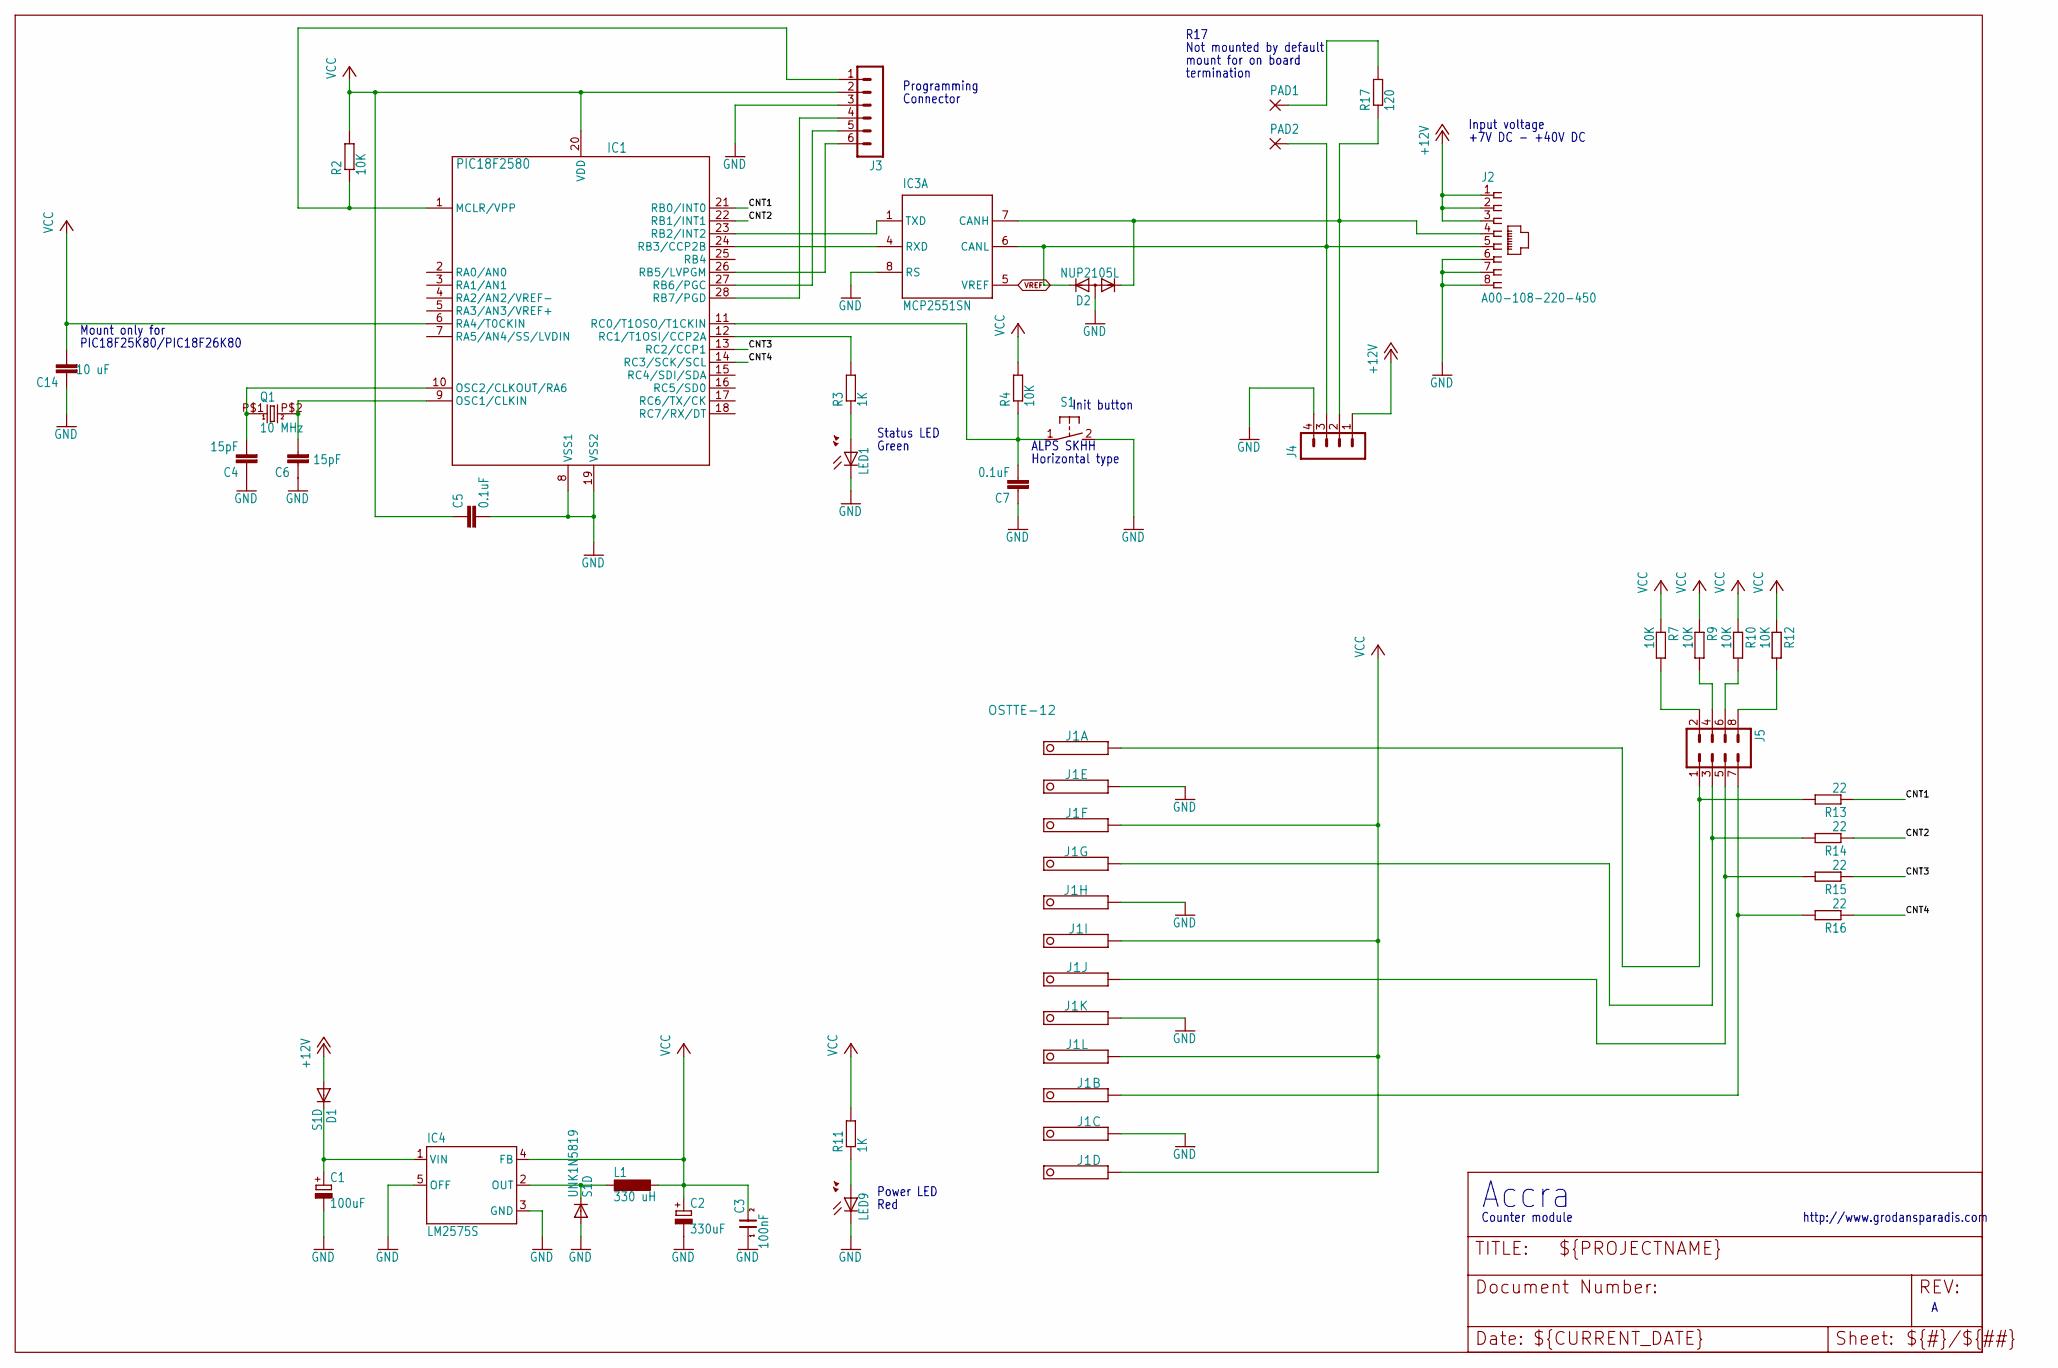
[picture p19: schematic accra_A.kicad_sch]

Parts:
C1: 100uF; PANASONIC_D
C2: 330uF; PANASONIC_D
C3: 100nF; 0805
C4, C6: 15pF; C0805
C5, C7: 0.1uF; C0805
C14: 10 uF; C0805
D1: S1D; SOD123
D2: NUP2105L; SOT23
IC1: PIC18F2580; SO28
IC3: MCP2551SN; SO-08
IC4: LM2575S; TO263-5
J1: OSTTE-12; PINHEAD-12
J2: A00-108-220-450; RJ-45
J3: MA06-1
J4: MA04-1
J5: MA04-2
L1: 330 uH; DO3316P
LED1, LED9: LEDCHIP-LED0805; CHIP-LED0805
PAD1, PAD2: 1,6/0,8; 1,6_0,8
Q1: 10 MHz; 9C
R2, R4, R7, R9, R10, R12: 10K; R0805
R3, R11: 1K; R0805
R13, R14, R15, R16: 22; R0805
R17: 120; R0805
S1: 31-XX; B3F-31XX
UNK1N5819: S1D; SOD123

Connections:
+12V: D1.A, J2.1, J2.2, J2.3, J4.1
CANL: D2.2 (K2), IC3.6 (CANL), J2.5, J4.3, PAD2.1
CNT1: IC1.21 (RB0/INT0), R13.1
CNT2: IC1.22 (RB1/INT1), R14.1
CNT3: IC1.13 (RC2/CCP1), R15.1
CNT4: IC1.14 (RC3/SCK/SCL), R16.1
GND: C1.-, C2.-, C3.1, C4.1, C5.2, C6.1, C7.1, C14.1, D2.3 (A), IC1.8 (VSS1), IC1.19 (VSS2), IC3.2 (VSS), IC3.8 (RS), IC4.3 (GND), IC4.5 (OFF), J1.2, J1.5, J1.8, J1.11, J2.6, J2.7, J2.8, J3.3, J4.4, LED1.C, LED9.C, S1.2 (S), UNK1N5819.A
unnamed: IC4.2 (OUT), L1.1, UNK1N5819.C
unnamed: C4.2, IC1.10 (OSC2/CLKOUT/RA6), Q1.P$1 (1)
unnamed: C1.+, D1.C, IC4.1 (VIN)
unnamed: IC1.12 (RC1/T1OSI/CCP2A), R3.2
unnamed: LED1.A, R3.1
unnamed: C7.2, IC1.11 (RC0/T1OSO/T1CKIN), R4.1, S1.1
unnamed: C6.2, IC1.9 (OSC1/CLKIN), Q1.P$2 (2)
unnamed: J1.4, J5.3, R14.2
unnamed: J1.7, J5.5, R15.2
unnamed: PAD1.1, R17.2
unnamed: IC1.1 (MCLR/VPP), J3.1, R2.1
unnamed: IC1.28 (RB7/PGD), J3.4
unnamed: IC1.27 (RB6/PGC), J3.5
unnamed: IC1.26 (RB5/LVPGM), J3.6
unnamed: J1.10, J5.7, R16.2
unnamed: J5.2, R7.2
unnamed: LED9.A, R11.1
unnamed: D2.1 (K1), IC3.7 (CANH), J2.4, J4.2, R17.1
unnamed: J5.4, R9.2
unnamed: J5.6, R10.2
unnamed: J5.8, R12.2
unnamed: J1.1, J5.1, R13.2
RXCAN: IC1.24 (RB3/CCP2B), IC3.4 (RXD)
TXCAN: IC1.23 (RB2/INT2), IC3.1 (TXD)
VCC: C2.+, C3.2, C5.1, C14.2, IC1.6 (RA4/T0CKIN), IC1.20 (VDD), IC3.3 (VDD), IC4.4 (FB), J1.3, J1.6, J1.9, J1.12, J3.2, L1.2, R2.2, R4.2, R7.1, R9.1, R10.1, R11.2, R12.1
VREF: IC3.5 (VREF)

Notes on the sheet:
Connector
PIC18F25K80/PIC18F26K80
Input voltage
Programming
Init button
Power LED
termination
http://www.grodansparadis.com
+7V DC - +40V DC
Red
Status LED
Green
Counter module
Mount only for
mount for on board
ALPS SKHH
Horizontal type
Accra
Not mounted by default
R17

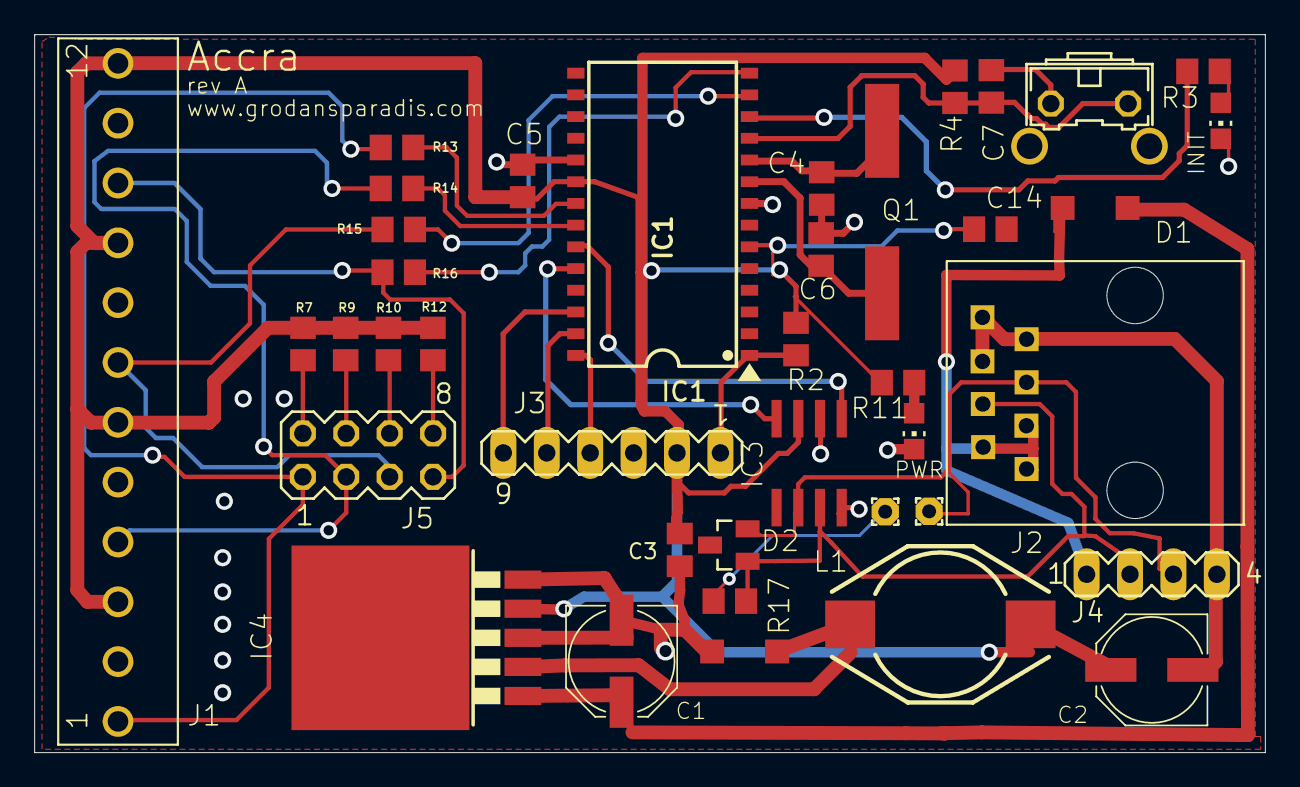
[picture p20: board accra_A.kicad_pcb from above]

Board: 6 copper layers, 72.0 x 42.0 mm, 39 parts (0 on the bottom side), 32 nets.

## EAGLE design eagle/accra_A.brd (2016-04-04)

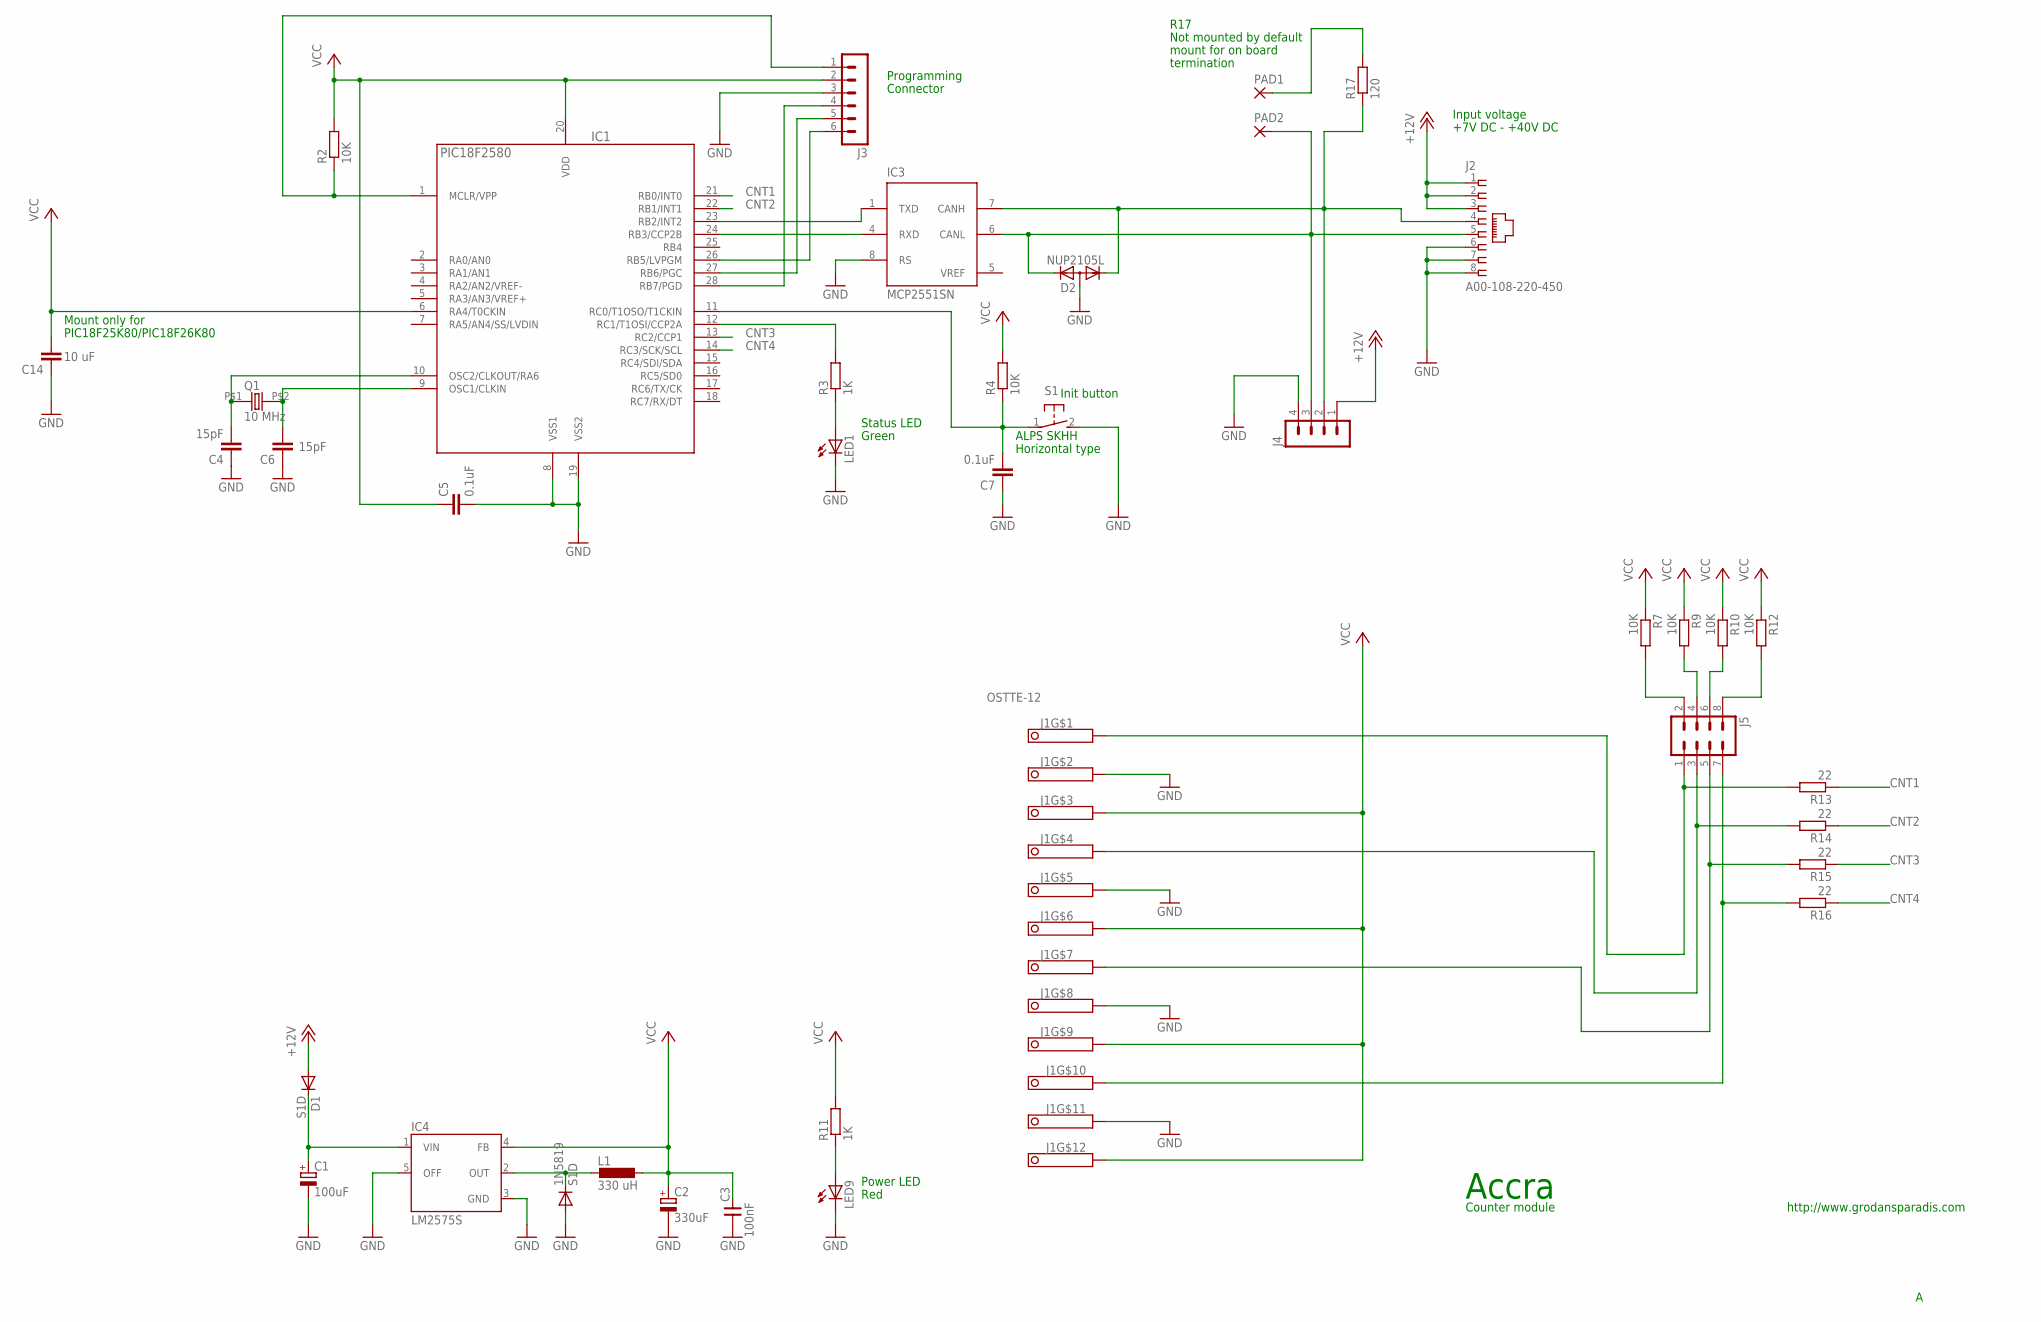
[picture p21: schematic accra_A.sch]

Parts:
1N5819: S1D; SOD123
C1: 100uF; PANASONIC_D
C2: 330uF; PANASONIC_D
C3: 100nF; 0805
C4, C6: 15pF; C0805
C5, C7: 0.1uF; C0805
C14: 10 uF; C0805
D1: S1D; SOD123
D2: NUP2105L; SOT23
IC1: PIC18F2580; SO28
IC3: MCP2551SN; SO-08
IC4: LM2575S; TO263-5
J1: OSTTE-12; PINHEAD-12
J2: A00-108-220-450; RJ-45
J3: MA06-1
J4: MA04-1
J5: MA04-2
L1: 330 uH; DO3316P
LED1, LED9: LEDCHIP-LED0805; CHIP-LED0805
PAD1, PAD2: 1,6/0,8
Q1: 10 MHz; 9C
R2, R4, R7, R9, R10, R12: 10K; R0805
R3, R11: 1K; R0805
R13, R14, R15, R16: 22; R0805
R17: 120; R0805
S1: 31-XX; B3F-31XX

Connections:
+12V: D1.A, J2.1, J2.2, J2.3, J4.1
CANL: D2.2 (K2), IC3.6 (CANL), J2.5, J4.3, PAD2.1
CNT1: IC1.21 (RB0/INT0), R13.1
CNT2: IC1.22 (RB1/INT1), R14.1
CNT3: IC1.13 (RC2/CCP1), R15.1
CNT4: IC1.14 (RC3/SCK/SCL), R16.1
GND: 1N5819.A, C1.-, C2.-, C3.1, C4.1, C5.2, C6.1, C7.1, C14.1, D2.3 (A), IC1.8 (VSS1), IC1.19 (VSS2), IC3.2 (VSS), IC3.8 (RS), IC4.3 (GND), IC4.5 (OFF), J1.2, J1.5, J1.8, J1.11, J2.6, J2.7, J2.8, J3.3, J4.4, LED1.C, LED9.C, S1.2 (S)
unnamed: 1N5819.C, IC4.2 (OUT), L1.1
unnamed: C4.2, IC1.10 (OSC2/CLKOUT/RA6), Q1.P$1 (1)
unnamed: C1.+, D1.C, IC4.1 (VIN)
unnamed: IC1.12 (RC1/T1OSI/CCP2A), R3.2
unnamed: LED1.A, R3.1
unnamed: C7.2, IC1.11 (RC0/T1OSO/T1CKIN), R4.1, S1.1
unnamed: C6.2, IC1.9 (OSC1/CLKIN), Q1.P$2 (2)
unnamed: J1.4, J5.3, R14.2
unnamed: J1.7, J5.5, R15.2
unnamed: PAD1.1, R17.2
unnamed: IC1.1 (MCLR/VPP), J3.1, R2.1
unnamed: IC1.28 (RB7/PGD), J3.4
unnamed: IC1.27 (RB6/PGC), J3.5
unnamed: IC1.26 (RB5/LVPGM), J3.6
unnamed: J1.10, J5.7, R16.2
unnamed: J5.2, R7.2
unnamed: LED9.A, R11.1
unnamed: D2.1 (K1), IC3.7 (CANH), J2.4, J4.2, R17.1
unnamed: J5.4, R9.2
unnamed: J5.6, R10.2
unnamed: J5.8, R12.2
unnamed: J1.1, J5.1, R13.2
RXCAN: IC1.24 (RB3/CCP2B), IC3.4 (RXD)
TXCAN: IC1.23 (RB2/INT2), IC3.1 (TXD)
VCC: C2.+, C3.2, C5.1, C14.2, IC1.6 (RA4/T0CKIN), IC1.20 (VDD), IC3.3 (VDD), IC4.4 (FB), J1.3, J1.6, J1.9, J1.12, J3.2, L1.2, R2.2, R4.2, R7.1, R9.1, R10.1, R11.2, R12.1
VREF: IC3.5 (VREF)

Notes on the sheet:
Init button
Status LED
Programming
Connector
ALPS SKHH
Horizontal type
Accra
http://www.grodansparadis.com
Counter module
Input voltage
+7V DC - +40V DC
Power LED
Red
Green
Mount only for
PIC18F25K80/PIC18F26K80
Not mounted by default
mount for on board
termination
R17

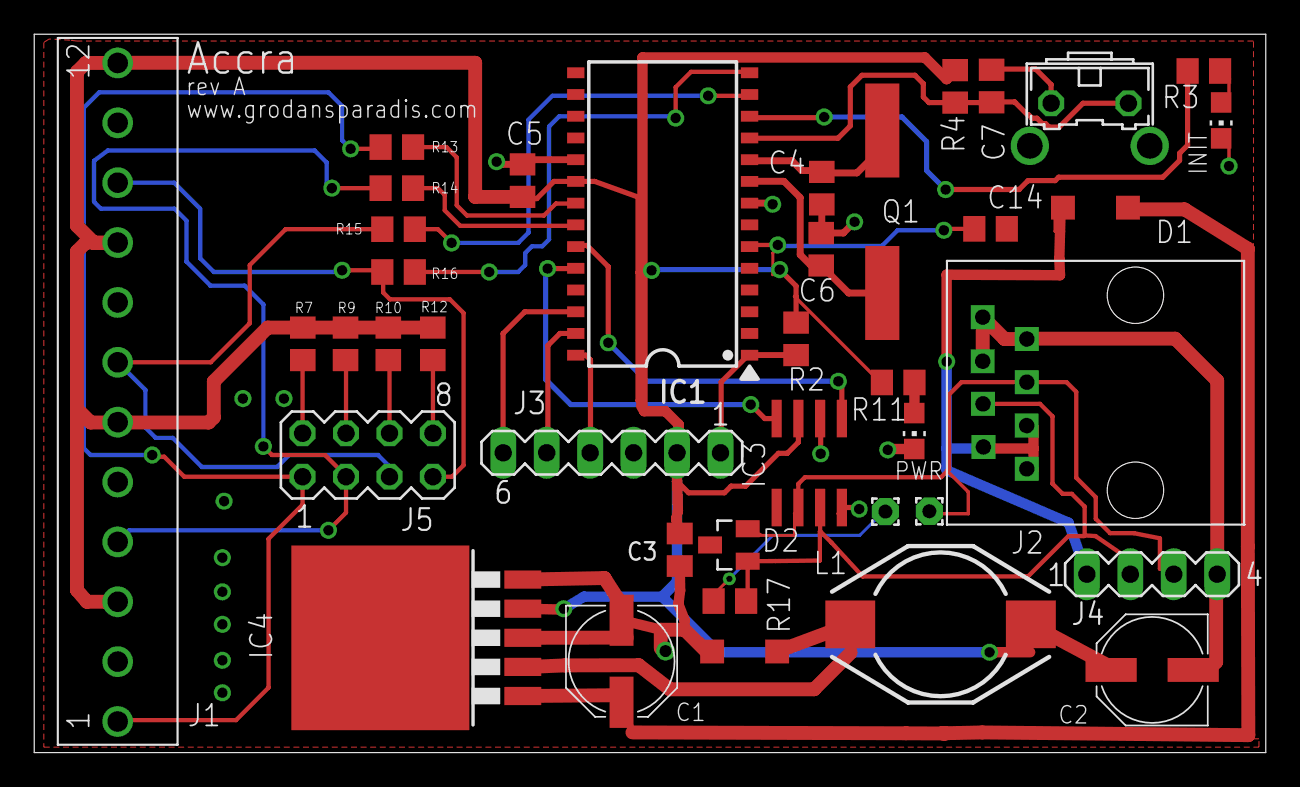
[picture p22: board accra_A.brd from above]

Board: 2 copper layers, 72.0 x 42.0 mm, 39 parts (0 on the bottom side), 32 nets.

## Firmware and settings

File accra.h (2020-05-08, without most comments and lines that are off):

#define ACCRA_H
#define	TRUE                    1
#define	FALSE                   0
#define TIMER0_RELOAD_VALUE		0xfb1d
#define TIMER2_RELOAD_VALUE		156
#define STATUS_LED              PORTCbits.RC1
#define INIT_BUTTON             PORTCbits.RC0
#define CHANNEL0                PORTBbits.RB0
#define CHANNEL1                PORTBbits.RB1
#define CHANNEL2                PORTCbits.RC2
#define CHANNEL3                PORTCbits.RC3
#define LATCH_CHANNEL0          LATBbits.LATB0
#define LATCH_CHANNEL1          LATBbits.LATB1
#define LATCH_CHANNEL2          LATCbits.LATC2
#define LATCH_CHANNEL3          LATCbits.LATC3
#define CHANNEL_DIRECTION_UP                0
#define CHANNEL_DIRECTION_DOWN              1
#define COUNTER_CTRL_DIRECTION              0x01    // Counting direction
#define COUNTER_CTRL_ALARM                  0x02    // Enable alarm level
#define COUNTER_CTRL_RELOAD_ZERO            0x04 	// Reload on zero
#define COUNTER_CTRL_ENABLED                0x80 	// Relay enabled
#define FREQ_CTRL_LOW_ALARM                 0x01    // Enable frequency low alarm
#define FREQ_CTRL_HIGH_ALARM                0x02    // Enable frequency high alarm
#define FREQ_CTRL_STREAM                    0x10    // Enable stream events
#define FREQ_CTRL_ENABLE                    0x80    // Enable Input.
#define MEASUREMENT_CTRL_CALCBASE           0x01    // 0 use counter, 1 use frequency
#define MEASUREMENT_CTRL_UNIT0              0x08    // Unit low bit
#define MEASUREMENT_CTRL_UNIT1              0x10    // Unit high bit
#define MEASUREMENT_CTRL_CLASS_BIT_8        0x40    // Bit 8 of the class
#define MEASUREMENT_CTRL_ENABLED            0x80    // Enable measuement calculations
#define MEASUREMENT_CTRL_UNIT_MASK          0b00011000
#define ALARM_COUNTER0                      0x01    // Counter 0 alarm
#define ALARM_COUNTER1                      0x02    // Counter 1 alarm
#define ALARM_COUNTER2                      0x04    // Counter 2 alarm
#define ALARM_COUNTER3                      0x08    // Counter 3 alarm
#define ALARM_FREQUENCY0                    0x10    // Frequency 0 alarm
#define ALARM_FREQUENCY1                    0x20    // Frequency 1 alarm
#define ALARM_FREQUENCY2                    0x40    // Frequency 2 alarm
#define ALARM_FREQUENCY3                    0x50    // Frequency 3 alarm
#define DEFAULT_COUNTER0_HYSTERESIS         200
#define DEFAULT_COUNTER1_HYSTERESIS         200
#define DEFAULT_COUNTER2_HYSTERESIS         200
#define DEFAULT_COUNTER3_HYSTERESIS         200
#define DEFAULT_FREQUENCY0_HYSTERESIS       50
#define DEFAULT_FREQUENCY1_HYSTERESIS       50
#define DEFAULT_FREQUENCY2_HYSTERESIS       50
#define DEFAULT_FREQUENCY3_HYSTERESIS       50
#define REG0_ACCRA_ZONE                             0
#define REG0_ACCRA_SUBZONE                          1
#define REG0_ACCRA_CH0_SUBZONE                      2
#define REG0_ACCRA_CH1_SUBZONE                      3
#define REG0_ACCRA_CH2_SUBZONE                      4
#define REG0_ACCRA_CH3_SUBZONE                      5
#define REG0_ACCRA_CONTROL_COUNTER_CH0              6
#define REG0_ACCRA_CONTROL_COUNTER_CH1              7
#define REG0_ACCRA_CONTROL_COUNTER_CH2              8
#define REG0_ACCRA_CONTROL_COUNTER_CH3              9
#define REG0_ACCRA_CONTROL_FREQ_CH0                 10
#define REG0_ACCRA_CONTROL_FREQ_CH1                 11
#define REG0_ACCRA_CONTROL_FREQ_CH2                 12
#define REG0_ACCRA_CONTROL_FREQ_CH3                 13
#define REG0_ACCRA_RESET_COUNTER_CH0                14  // Not stored in EEPROM
#define REG0_ACCRA_RESET_COUNTER_CH1                15  // Not stored in EEPROM
#define REG0_ACCRA_RESET_COUNTER_CH2                16  // Not stored in EEPROM
#define REG0_ACCRA_RESET_COUNTER_CH3                17  // Not stored in EEPROM
#define REG0_ACCRA_COUNTER_CH0_MSB                  18  // Not stored in EEPROM  *
#define REG0_ACCRA_COUNTER_CH0_0                    18  // Not stored in EEPROM
#define REG0_ACCRA_COUNTER_CH0_1                    19  // Not stored in EEPROM
#define REG0_ACCRA_COUNTER_CH0_2                    20  // Not stored in EEPROM
#define REG0_ACCRA_COUNTER_CH0_3                    21  // Not stored in EEPROM
#define REG0_ACCRA_COUNTER_CH0_LSB                  21  // Not stored in EEPROM
#define REG0_ACCRA_COUNTER_CH1_MSB                  22  // Not stored in EEPROM
#define REG0_ACCRA_COUNTER_CH1_0                    22  // Not stored in EEPROM
#define REG0_ACCRA_COUNTER_CH1_1                    23  // Not stored in EEPROM
#define REG0_ACCRA_COUNTER_CH1_2                    24  // Not stored in EEPROM
#define REG0_ACCRA_COUNTER_CH1_3                    25  // Not stored in EEPROM
#define REG0_ACCRA_COUNTER_CH1_LSB                  25  // Not stored in EEPROM
#define REG0_ACCRA_COUNTER_CH2_MSB                  26  // Not stored in EEPROM
#define REG0_ACCRA_COUNTER_CH2_0                    26  // Not stored in EEPROM
#define REG0_ACCRA_COUNTER_CH2_1                    27  // Not stored in EEPROM
#define REG0_ACCRA_COUNTER_CH2_2                    28  // Not stored in EEPROM
#define REG0_ACCRA_COUNTER_CH2_3                    29  // Not stored in EEPROM
#define REG0_ACCRA_COUNTER_CH2_LSB                  29  // Not stored in EEPROM
#define REG0_ACCRA_COUNTER_CH3_MSB                  30  // Not stored in EEPROM
#define REG0_ACCRA_COUNTER_CH3_0                    30  // Not stored in EEPROM
#define REG0_ACCRA_COUNTER_CH3_1                    31  // Not stored in EEPROM
#define REG0_ACCRA_COUNTER_CH3_2                    32  // Not stored in EEPROM
#define REG0_ACCRA_COUNTER_CH3_3                    33  // Not stored in EEPROM
#define REG0_ACCRA_COUNTER_CH3_LSB                  33  // Not stored in EEPROM
#define REG0_ACCRA_COUNTER_ALARM_CH0_MSB            34  // *
#define REG0_ACCRA_COUNTER_ALARM_CH0_0              34
#define REG0_ACCRA_COUNTER_ALARM_CH0_1              35
#define REG0_ACCRA_COUNTER_ALARM_CH0_2              36
#define REG0_ACCRA_COUNTER_ALARM_CH0_3              37
#define REG0_ACCRA_COUNTER_ALARM_CH0_LSB            37
#define REG0_ACCRA_COUNTER_ALARM_CH1_MSB            38
#define REG0_ACCRA_COUNTER_ALARM_CH1_0              38
#define REG0_ACCRA_COUNTER_ALARM_CH1_1              39
#define REG0_ACCRA_COUNTER_ALARM_CH1_2              40
#define REG0_ACCRA_COUNTER_ALARM_CH1_3              41
#define REG0_ACCRA_COUNTER_ALARM_CH1_LSB            41
#define REG0_ACCRA_COUNTER_ALARM_CH2_MSB            42
#define REG0_ACCRA_COUNTER_ALARM_CH2_0              42
#define REG0_ACCRA_COUNTER_ALARM_CH2_1              43
#define REG0_ACCRA_COUNTER_ALARM_CH2_2              44
#define REG0_ACCRA_COUNTER_ALARM_CH2_3              45
#define REG0_ACCRA_COUNTER_ALARM_CH2_LSB            45
#define REG0_ACCRA_COUNTER_ALARM_CH3_MSB            46
#define REG0_ACCRA_COUNTER_ALARM_CH3_0              46
#define REG0_ACCRA_COUNTER_ALARM_CH3_1              47
#define REG0_ACCRA_COUNTER_ALARM_CH3_2              48
#define REG0_ACCRA_COUNTER_ALARM_CH3_3              49
#define REG0_ACCRA_COUNTER_ALARM_CH3_LSB            49
#define REG0_ACCRA_COUNTER_RELOAD_CH0_MSB           50  // *
#define REG0_ACCRA_COUNTER_RELOAD_CH0_0             50
#define REG0_ACCRA_COUNTER_RELOAD_CH0_1             51
#define REG0_ACCRA_COUNTER_RELOAD_CH0_2             52
#define REG0_ACCRA_COUNTER_RELOAD_CH0_3             53
#define REG0_ACCRA_COUNTER_RELOAD_CH0_LSB           53
#define REG0_ACCRA_COUNTER_RELOAD_CH1_MSB           54
#define REG0_ACCRA_COUNTER_RELOAD_CH1_0             54
#define REG0_ACCRA_COUNTER_RELOAD_CH1_1             55
#define REG0_ACCRA_COUNTER_RELOAD_CH1_2             56
#define REG0_ACCRA_COUNTER_RELOAD_CH1_3             57
#define REG0_ACCRA_COUNTER_RELOAD_CH1_LSB           57
#define REG0_ACCRA_COUNTER_RELOAD_CH2_MSB           58
#define REG0_ACCRA_COUNTER_RELOAD_CH2_0             58
#define REG0_ACCRA_COUNTER_RELOAD_CH2_1             59
#define REG0_ACCRA_COUNTER_RELOAD_CH2_2             60
#define REG0_ACCRA_COUNTER_RELOAD_CH2_3             61
#define REG0_ACCRA_COUNTER_RELOAD_CH2_LSB           61
#define REG0_ACCRA_COUNTER_RELOAD_CH3_MSB           62
#define REG0_ACCRA_COUNTER_RELOAD_CH3_0             62
#define REG0_ACCRA_COUNTER_RELOAD_CH3_1             63
#define REG0_ACCRA_COUNTER_RELOAD_CH3_2             64
#define REG0_ACCRA_COUNTER_RELOAD_CH3_3             65
#define REG0_ACCRA_COUNTER_RELOAD_CH3_LSB           65
#define REG0_ACCRA_COUNTER_HYSTERESIS_CH0_MSB       66
#define REG0_ACCRA_COUNTER_HYSTERESIS_CH0_LSB       67
#define REG0_ACCRA_COUNTER_HYSTERESIS_CH1_MSB       68
#define REG0_ACCRA_COUNTER_HYSTERESIS_CH1_LSB       69
#define REG0_ACCRA_COUNTER_HYSTERESIS_CH2_MSB       70
#define REG0_ACCRA_COUNTER_HYSTERESIS_CH2_LSB       71
#define REG0_ACCRA_COUNTER_HYSTERESIS_CH3_MSB       72
#define REG0_ACCRA_COUNTER_HYSTERESIS_CH3_LSB       73
#define REG0_ACCRA_COUNTER_REPORT_INTERVAL_CH0      74
#define REG0_ACCRA_COUNTER_REPORT_INTERVAL_CH1      75
#define REG0_ACCRA_COUNTER_REPORT_INTERVAL_CH2      76
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

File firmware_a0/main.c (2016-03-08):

/* ******************************************************************************
 * 	VSCP (Very Simple Control Protocol) 
 * 	http://www.vscp.org
 *
 *  Smart Relay Module
 * 	Version: See project header
 * 	akhe@eurosource.se
 *
 *  Copyright (C) 1995-2012 Ake Hedman, Grodans Paradis AB
 *                      <akhe@grodansparadis.com>
 *
 * This software is provided 'as-is', without any express or implied
 * warranty.  In no event will the authors be held liable for any damages
 * arising from the use of this software.
 *
 * Permission is granted to anyone to use this software for any purpose,
 * including commercial applications, and to alter it and redistribute it
 * freely, subject to the following restrictions:
 *
 * 1. The origin of this software must not be misrepresented; you must not
 *    claim that you wrote the original software. If you use this software
 *    in a product, an acknowledgment in the product documentation would be
 *    appreciated but is not required.
 * 2. Altered source versions must be plainly marked as such, and must not be
 *    misrepresented as being the original software.
 * 3. This notice may not be removed or altered from any source distribution.
 * 
 *	This file is part of VSCP - Very Simple Control Protocol 	
 *	http://www.vscp.org
 *
 * ******************************************************************************
 */

#include <p18cxxx.h>
#include <timers.h>
#include <delays.h>
#include <eeprom.h>
#include <inttypes.h>
#include <ecan.h>
#include <vscp_firmware.h>
#include <vscp_class.h>
#include <vscp_type.h>
#include "main.h"
#include "version.h"
#include "smartrelay.h"
#include "main.h" 


#if defined(RELEASE)

#pragma config WDT = ON, WDTPS = 128
#pragma config OSC = HSPLL
#pragma config BOREN = BOACTIVE
#pragma config STVREN = ON
#pragma config BORV = 3
#pragma config LVP = ON
#pragma config CPB = ON

#else

#pragma config WDT = OFF
#pragma config OSC = HSPLL
#pragma config PWRT = ON
#pragma config BOREN = BOACTIVE
#pragma config STVREN = ON
#pragma config BORV = 3
#pragma config LVP = OFF
#pragma config CPB = OFF

#endif

// Startup code from c018.c
void _startup(void);

// ISR Routines
void isr_low(void);

extern const rom int log_Table[]; // log10 for Hummidity measurement

// The device URL (max 32 characters including null termination)
const uint8_t vscp_deviceURL[] = "www.eurosource.se/paris_002.xml";

volatile unsigned long measurement_clock; // Clock for measurments

BYTE seconds; // counter for seconds
BYTE minutes; // counter for minutes
BYTE hours; // Counter for hours

// bit 0 - Relay 0 etc
// Bit set for pulsed relay
unsigned char relay_pulse_flags;

unsigned short relay_pulse_timer[8];
unsigned short relay_protection_timer[8];


///////////////////////////////////////////////////////////////////////////////
// Isr() 	- Interrupt Service Routine
//      	- Services Timer0 Overflow
//      	- Services GP3 Pin Change
//////////////////////////////////////////////////////////////////////////////

#ifdef RELOCATE
#pragma code low_vector = 0x208
#else
#pragma code low_vector = 0x08
#endif

void interrupt_at_low_vector(void) {
    _asm GOTO isr_low _endasm
}

#pragma code

#pragma interrupt isr_low 

void isr_low(void) {
    BYTE temp;
    unsigned short tval0, tval1;
    char *p;

    tval0 += 1;

    // Clock
    if (PIR1bits.TMR2IF) { // If a Timer2 Interrupt, Then...

        vscp_timer++;
        measurement_clock++;

        // Check for init button
        if (PORTCbits.RC0) {
            vscp_initbtncnt = 0;
        } else {
            // Active
            vscp_initbtncnt++;
        }

        // Status LED
        vscp_statuscnt++;
        if ((VSCP_LED_BLINK1 == vscp_initledfunc) && (vscp_statuscnt > 100)) {

            if (PORTCbits.RC1) {
                PORTCbits.RC1 = 0;
            } else {
                PORTCbits.RC1 = 1;
            }

            vscp_statuscnt = 0;

        } else if (VSCP_LED_ON == vscp_initledfunc) {
            PORTCbits.RC1 = 1;
            vscp_statuscnt = 0;
        } else if (VSCP_LED_OFF == vscp_initledfunc) {
            PORTCbits.RC1 = 0;
            vscp_statuscnt = 0;
        }

        PIR1bits.TMR2IF = 0; // Clear Timer0 Interrupt Flag

    }

    /*
            // CAN error
            if ( PIR3bits.ERRIF ) {
		
                    temp = COMSTAT;
                    PIR3 = 0;
		
            }
     */
    return;
}


//***************************************************************************
// Main() - Main Routine
//***************************************************************************

void main() {
    unsigned char a;
    unsigned char i;
    unsigned char ttt;

    init(); // Initialize Microcontroller

    // Check VSCP persistent storage and
    // restore if needed
    if (!vscp_check_pstorage()) {

        // Spoiled or not initialized - reinitialize
        init_app_eeprom();

    }

    vscp_init(); // Initialize the VSCP functionality


    while (1) { // Loop Forever


        ClrWdt(); // Feed the dog


        if ((vscp_initbtncnt > 250) && (VSCP_STATE_INIT != vscp_node_state)) {
            // Init button pressed
            vscp_nickname = VSCP_ADDRESS_FREE;
            writeEEPROM(VSCP_EEPROM_NICKNAME, VSCP_ADDRESS_FREE);
            vscp_init();
        }

        // Check for a valid  event
        vscp_imsg.flags = 0;
        vscp_getEvent();

        // do a meaurement if needed
        if (measurement_clock > 1000) {

            measurement_clock = 0;
            //measurement_seconds++;

            // Do VSCP one second jobs
            vscp_doOneSecondWork();

            // Temperature report timers are only updated if in active
            // state guid_reset
            if (VSCP_STATE_ACTIVE == vscp_node_state) {

                // Do VSCP one second jobs
                doApplicationOneSecondWork();
            }

            // If we have errors in sensor readings
            // send out error event
            //if ( error_cnt_tempsensor0 || error_cnt_tempsensor1 ) {
            //	sendErrorEvent( ERROR_SENSOR );
            //}

        }

        if (seconds > 59) {

            seconds = 0;
            minutes++;

            if (minutes > 59) {
                minutes = 0;
                hours++;
            }

            if (hours > 23) hours = 0;

        }

        switch (vscp_node_state) {

            case VSCP_STATE_STARTUP: // Cold/warm reset

                // Get nickname from EEPROM
                if (VSCP_ADDRESS_FREE == vscp_nickname) {
                    // new on segment need a nickname
                    vscp_node_state = VSCP_STATE_INIT;
                } else {
                    // been here before - go on
                    vscp_node_state = VSCP_STATE_ACTIVE;
                    vscp_goActiveState();
                }
                break;

            case VSCP_STATE_INIT: // Assigning nickname
                vscp_handleProbeState();
                break;

            case VSCP_STATE_PREACTIVE: // Waiting for host initialisation
                vscp_goActiveState();
                break;

            case VSCP_STATE_ACTIVE: // The normal state

                if (vscp_imsg.flags & VSCP_VALID_MSG) { // incoming message?

                    vscp_handleProtocolEvent();
                    doDM(); // Feed DM

                }
                break;

            case VSCP_STATE_ERROR: // Everything is *very* *very* bad.
                vscp_error();
                break;

            default: // Should not be here...
                vscp_node_state = VSCP_STATE_STARTUP;
                break;

        }

        doWork();



    } // while
}

///////////////////////////////////////////////////////////////////////////////
// Init - Initialization Routine
//  

void init() {

    uint8_t msgdata[ 8 ];

    // Initialize data
    init_app_ram();

    // Initialize the uP

    // PORTB
    // RA0/AN0 - input
    // RA1/AN1 - input
    // RA2/AN2 - input
    TRISA = 0x07;

    // PortB
    // RB7 - Not used.
    // RB& - Not used.
    // RB5 - Not used.
    // RB4/AN9 - input
    // RB3 CAN RX - input
    // RB2 CAN TX - output
    // RB1/AN8 - input
    // RB0/AN10 -input
    TRISB = 0x1B;

    // RC0 - Input  - Init button
    // RC1 - Output - Status LED - Default off
    // RC2 - Output - Not used.
    // RC3 - Output - Not used.
    // RC5 - Output - Not used.
    // RC6 - Output - Not used.
    // RC7 - Output - Not used.
    TRISC = 0x01;
    PORTC = 0x00;

    // Sensor 0 timer
    OpenTimer0(TIMER_INT_OFF &
            T0_16BIT &
            T0_PS_1_2 &
            T0_SOURCE_INT);

    // Sensor 1 timer
    OpenTimer1(TIMER_INT_OFF &
            T1_16BIT_RW &
            T1_SOURCE_INT &
            T1_PS_1_1 &
            T1_OSC1EN_OFF &
            T1_SYNC_EXT_OFF);

    // Timer 2 is used as a 1 ms clock
    // 156 is loaded eight time to give ~1250 cycles
    PR2 = TIMER2_RELOAD_VALUE; // Set reload value
    OpenTimer2(TIMER_INT_ON &
            T2_PS_1_4 &
            T2_POST_1_16);

    // Initialize all relays in off pos
    PORTCbits.RC7 = 0;
    PORTAbits.RA5 = 0;
    PORTAbits.RA4 = 0;
    PORTAbits.RA3 = 0;
    PORTAbits.RA2 = 0;
    PORTAbits.RA1 = 0;
    PORTAbits.RA0 = 0;
    PORTCbits.RC5 = 0;

    // Initialize CAN
    ECANInitialize();

    // Must be in Config mode to change many of settings.
    //ECANSetOperationMode(ECAN_OP_MODE_CONFIG);

    // Return to Normal mode to communicate.
    //ECANSetOperationMode(ECAN_OP_MODE_NORMAL);

    /*
        msgdata[ 0 ] = 1;
            msgdata[ 1 ] = 2;
            msgdata[ 2 ] = 3;
            msgdata[ 3 ] = 4;

            if ( vscp18f_sendMsg( 0x123,  msgdata, 4, CAN_TX_PRIORITY_0 & CAN_TX_XTD_FRAME & CAN_TX_NO_RTR_FRAME ) ) {
                    ;
            }

     */

    // Enable peripheral interrupt
    INTCONbits.PEIE = 1;

    // Enable global interrupt
    INTCONbits.GIE = 1;

    return;
}

///////////////////////////////////////////////////////////////////////////////
// init_app_ram
//

void init_app_ram(void) {
    unsigned char i;

    measurement_clock = 0; // start a new meaurement cycle

    seconds = 0;
    minutes = 0;
    hours = 0;

    relay_pulse_flags = 0; // No pulse outputs yet

    // Clear timers
    for (i = 0; i < 8; i++) {
        relay_pulse_timer[ i ] = 0;
        relay_protection_timer[ i ] = 0;
    }
}


///////////////////////////////////////////////////////////////////////////////
// init_app_eeprom
//

void init_app_eeprom(void) {
    unsigned char i, j;

    writeEEPROM(VSCP_EEPROM_END + REG_RELAY_CONTROL0, RELAY_CONTROLBIT_ONEVENT |
            RELAY_CONTROLBIT_OFFEVENT |
            RELAY_CONTROLBIT_ENABLED);

    writeEEPROM(VSCP_EEPROM_END + REG_RELAY_CONTROL1, RELAY_CONTROLBIT_ONEVENT |
            RELAY_CONTROLBIT_OFFEVENT |
            RELAY_CONTROLBIT_ENABLED);

    writeEEPROM(VSCP_EEPROM_END + REG_RELAY_CONTROL2, RELAY_CONTROLBIT_ONEVENT |
            RELAY_CONTROLBIT_OFFEVENT |
            RELAY_CONTROLBIT_ENABLED);

    writeEEPROM(VSCP_EEPROM_END + REG_RELAY_CONTROL3, RELAY_CONTROLBIT_ONEVENT |
            RELAY_CONTROLBIT_OFFEVENT |
            RELAY_CONTROLBIT_ENABLED);

    writeEEPROM(VSCP_EEPROM_END + REG_RELAY_CONTROL4, RELAY_CONTROLBIT_ONEVENT |
            RELAY_CONTROLBIT_OFFEVENT |
            RELAY_CONTROLBIT_ENABLED);

    writeEEPROM(VSCP_EEPROM_END + REG_RELAY_CONTROL5, RELAY_CONTROLBIT_ONEVENT |
            RELAY_CONTROLBIT_OFFEVENT |
            RELAY_CONTROLBIT_ENABLED);

    writeEEPROM(VSCP_EEPROM_END + REG_RELAY_CONTROL6, RELAY_CONTROLBIT_ONEVENT |
            RELAY_CONTROLBIT_OFFEVENT |
            RELAY_CONTROLBIT_ENABLED);

    writeEEPROM(VSCP_EEPROM_END + REG_RELAY_CONTROL7, RELAY_CONTROLBIT_ONEVENT |
            RELAY_CONTROLBIT_OFFEVENT |
            RELAY_CONTROLBIT_ENABLED);

    writeEEPROM(VSCP_EEPROM_END + REG_RELAY_PULSE_TIME_MSB0, 0);
    writeEEPROM(VSCP_EEPROM_END + REG_RELAY_PULSE_TIME_LSB0, 0);
    writeEEPROM(VSCP_EEPROM_END + REG_RELAY_PULSE_TIME_MSB1, 0);
    writeEEPROM(VSCP_EEPROM_END + REG_RELAY_PULSE_TIME_LSB1, 0);
    writeEEPROM(VSCP_EEPROM_END + REG_RELAY_PULSE_TIME_MSB2, 0);
    writeEEPROM(VSCP_EEPROM_END + REG_RELAY_PULSE_TIME_LSB2, 0);
    writeEEPROM(VSCP_EEPROM_END + REG_RELAY_PULSE_TIME_MSB3, 0);
    writeEEPROM(VSCP_EEPROM_END + REG_RELAY_PULSE_TIME_LSB3, 0);
    writeEEPROM(VSCP_EEPROM_END + REG_RELAY_PULSE_TIME_MSB4, 0);
    writeEEPROM(VSCP_EEPROM_END + REG_RELAY_PULSE_TIME_LSB4, 0);
    writeEEPROM(VSCP_EEPROM_END + REG_RELAY_PULSE_TIME_MSB5, 0);
    writeEEPROM(VSCP_EEPROM_END + REG_RELAY_PULSE_TIME_LSB5, 0);
    writeEEPROM(VSCP_EEPROM_END + REG_RELAY_PULSE_TIME_MSB6, 0);
    writeEEPROM(VSCP_EEPROM_END + REG_RELAY_PULSE_TIME_LSB6, 0);
    writeEEPROM(VSCP_EEPROM_END + REG_RELAY_PULSE_TIME_MSB7, 0);
    writeEEPROM(VSCP_EEPROM_END + REG_RELAY_PULSE_TIME_LSB7, 0);

    writeEEPROM(VSCP_EEPROM_END + REG_RELAY_PROTECTION_TIME_MSB0, 0);
    writeEEPROM(VSCP_EEPROM_END + REG_RELAY_PROTECTION_TIME_LSB0, 0);
    writeEEPROM(VSCP_EEPROM_END + REG_RELAY_PROTECTION_TIME_MSB1, 0);
    writeEEPROM(VSCP_EEPROM_END + REG_RELAY_PROTECTION_TIME_LSB1, 0);
    writeEEPROM(VSCP_EEPROM_END + REG_RELAY_PROTECTION_TIME_MSB2, 0);
    writeEEPROM(VSCP_EEPROM_END + REG_RELAY_PROTECTION_TIME_LSB2, 0);
    writeEEPROM(VSCP_EEPROM_END + REG_RELAY_PROTECTION_TIME_MSB3, 0);
    writeEEPROM(VSCP_EEPROM_END + REG_RELAY_PROTECTION_TIME_LSB3, 0);
    writeEEPROM(VSCP_EEPROM_END + REG_RELAY_PROTECTION_TIME_MSB4, 0);
    writeEEPROM(VSCP_EEPROM_END + REG_RELAY_PROTECTION_TIME_LSB4, 0);
    writeEEPROM(VSCP_EEPROM_END + REG_RELAY_PROTECTION_TIME_MSB5, 0);
    writeEEPROM(VSCP_EEPROM_END + REG_RELAY_PROTECTION_TIME_LSB5, 0);
    writeEEPROM(VSCP_EEPROM_END + REG_RELAY_PROTECTION_TIME_MSB6, 0);
    writeEEPROM(VSCP_EEPROM_END + REG_RELAY_PROTECTION_TIME_LSB6, 0);
    writeEEPROM(VSCP_EEPROM_END + REG_RELAY_PROTECTION_TIME_MSB7, 0);
    writeEEPROM(VSCP_EEPROM_END + REG_RELAY_PROTECTION_TIME_LSB7, 0);

    writeEEPROM(VSCP_EEPROM_END + REG_RELAY1_SUBZONE, 0);
    writeEEPROM(VSCP_EEPROM_END + REG_RELAY2_SUBZONE, 0);
    writeEEPROM(VSCP_EEPROM_END + REG_RELAY3_SUBZONE, 0);
    writeEEPROM(VSCP_EEPROM_END + REG_RELAY4_SUBZONE, 0);
    writeEEPROM(VSCP_EEPROM_END + REG_RELAY5_SUBZONE, 0);
    writeEEPROM(VSCP_EEPROM_END + REG_RELAY6_SUBZONE, 0);
    writeEEPROM(VSCP_EEPROM_END + REG_RELAY7_SUBZONE, 0);
    writeEEPROM(VSCP_EEPROM_END + REG_RELAY8_SUBZONE, 0);

    writeEEPROM(VSCP_EEPROM_END + EEPROM_SUBZONE, 0);

    // * * * Decision Matrix * * *
    // All elements disabled.
    for (i = 0; i < DESCION_MATRIX_ELEMENTS; i++) {
        for (j = 0; j < 8; j++) {
            writeEEPROM(VSCP_EEPROM_END + REG_DESCION_MATRIX + i * 8 + j, 0);
        }
    }

}

///////////////////////////////////////////////////////////////////////////////
// doApplicationOneSecondWork
//

void doApplicationOneSecondWork(void) {
    uint8_t i;
    uint8_t ctrlreg; // Current control register
    BOOL bOn;

    for (i = 0; i < 8; i++) {

        // Get control register for this relay
        ctrlreg = readEEPROM(VSCP_EEPROM_END + REG_RELAY_CONTROL0 + i);

        // If not enabled check next
        if (!(ctrlreg & RELAY_CONTROLBIT_ENABLED)) continue;

        if (relay_protection_timer[ i ]) {

            relay_protection_timer[ i ]--;

            // Check if its time to act on protection time
            if (!relay_protection_timer[ i ] &&
                    (readEEPROM(VSCP_EEPROM_END + REG_RELAY_CONTROL0 + i) & RELAY_CONTROLBIT_PROTECTION)) {

                // Yes - its time to protect this relay
                doActionOff(0, (1 << i));

                // Should alarm be sent?
                if (ctrlreg & RELAY_CONTROLBIT_ALARM) {
                    SendInformationEvent(i, VSCP_CLASS1_ALARM, VSCP_TYPE_ALARM_ALARM);
                }

            }
        }

        // Handle pulsed relays
        if (relay_pulse_flags & (1 << i)) {

            if (relay_pulse_timer[ i ]) {

                relay_pulse_timer[ i ]--;

                // If zero its time for state change
                if (!relay_pulse_timer[ i ]) {

                    switch (i) {

                        case 0:
                            if (PORTCbits.RC7) {
                                PORTCbits.RC7 = 0;
                                bOn = FALSE;
                            } else {
                                PORTCbits.RC7 = 1;
                                bOn = TRUE;
                            }
                            break;

                        case 1:
                            if (PORTAbits.RA5) {
                                PORTAbits.RA5 = 0;
                                bOn = FALSE;
                            } else {
                                PORTAbits.RA5 = 1;
                                bOn = TRUE;
                            }
                            break;

                        case 2:
                            if (PORTAbits.RA4) {
                                PORTAbits.RA4 = 0;
                                bOn = FALSE;
                            } else {
                                PORTAbits.RA4 = 1;
                                bOn = TRUE;
                            }
                            break;

                        case 3:
                            if (PORTAbits.RA3) {
                                PORTAbits.RA3 = 0;
                                bOn = FALSE;
                            } else {
                                PORTAbits.RA3 = 1;
                                bOn = TRUE;
                            }
                            break;

                        case 4:
                            if (PORTAbits.RA2) {
                                PORTAbits.RA2 = 0;
                                bOn = FALSE;
                            } else {
                                PORTAbits.RA2 = 1;
                                bOn = TRUE;
                            }
                            break;

                        case 5:
                            if (PORTAbits.RA1) {
                                PORTAbits.RA1 = 0;
                                bOn = FALSE;
                            } else {
                                PORTAbits.RA1 = 1;
                                bOn = TRUE;
                            }
                            break;

                        case 6:
                            if (PORTAbits.RA0) {
                                PORTAbits.RA0 = 0;
                                bOn = FALSE;
                            } else {
                                PORTAbits.RA0 = 1;
                                bOn = TRUE;
                            }
                            break;

                        case 7:
                            if (PORTCbits.RC5) {
                                PORTCbits.RC5 = 0;
                                bOn = FALSE;
                            } else {
                                PORTCbits.RC5 = 1;
                                bOn = TRUE;
                            }
                            break;
                    }

                    // Reload timer
                    relay_pulse_timer[ i ] =
                            readEEPROM(VSCP_EEPROM_END +
                            REG_RELAY_PULSE_TIME_MSB0 + 2 * i) *
                            256 +
                            readEEPROM(VSCP_EEPROM_END +
                            REG_RELAY_PULSE_TIME_LSB0 + 2 * i);

                    if (bOn) {

                        if (ctrlreg & RELAY_CONTROLBIT_ONEVENT) {
                            SendInformationEvent(i, VSCP_CLASS1_INFORMATION, VSCP_TYPE_INFORMATION_ON);
                        }

                        if (ctrlreg & RELAY_CONTROLBIT_STARTEVENT) {
                            SendInformationEvent(i, VSCP_CLASS1_INFORMATION, VSCP_TYPE_INFORMATION_START);
                        }

                    } else {

                        if (ctrlreg & RELAY_CONTROLBIT_OFFEVENT) {
                            SendInformationEvent(i, VSCP_CLASS1_INFORMATION, VSCP_TYPE_INFORMATION_OFF);
                        }

                        if (ctrlreg & RELAY_CONTROLBIT_STOPEVENT) {
                            SendInformationEvent(i, VSCP_CLASS1_INFORMATION, VSCP_TYPE_INFORMATION_STOP);
                        }
                    }

                } // State change

            } // Something to count down

        } // Pulse bit

    } // for all relays
}



///////////////////////////////////////////////////////////////////////////////
// Get Major version number for this hardware module
//

unsigned char getMajorVersion() {
    return FIRMWARE_MAJOR_VERSION;
}

///////////////////////////////////////////////////////////////////////////////
// Get Minor version number for this hardware module
//

unsigned char getMinorVersion() {
    return FIRMWARE_MINOR_VERSION;
}

///////////////////////////////////////////////////////////////////////////////
// Get Subminor version number for this hardware module
//

unsigned char getSubMinorVersion() {
    return FIRMWARE_SUB_MINOR_VERSION;
}

///////////////////////////////////////////////////////////////////////////////
// Get GUID from EEPROM
//

#ifdef GUID_IN_EEPROM

unsigned char getGuidFromEEprom(unsigned char idx) {
    readEEPROM(EEPROM_REG_GUIID0 + idx);
}
#endif

///////////////////////////////////////////////////////////////////////////////
// Get Manufacturer id and subid from EEPROM
//

#ifdef MANUFACTURER_INFO_IN_EEPROM

unsigned char getManufacturerIdFromEEprom(unsigned char idx) {
    readEEPROM(EEPROM_REG_MANUFACTUR_ID0 + idx);
}
#endif

///////////////////////////////////////////////////////////////////////////////
// Get the bootloader algorithm code
//

unsigned char getBootLoaderAlgorithm(void) {
    return VSCP_BOOTLOADER_PIC1;
}
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

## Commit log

2015-06-15 Initial checkin
    [accra001.brd, accra001.sch, accra002.brd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]
2015-07-27 Fixed problem with send timeout
    [accra.h, main.c]
2015-11-16 Ground functionality in place
2015-12-02 Added marker for pin 1
2015-12-17 Changed copyright info in headers so it is correct
    [accra.h, main.c]
2016-03-02 Fixed code for new firmware code
    [main.c]
2016-03-08 Adopted to 1.6 firmware. Adopted for PIC18F26K80.
    [accra_A.brd, accra_A.sch, accra_a0_B.brd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]
2016-04-04 Changed value of C14 to 10uF
    [accra_A.brd, accra_A.sch]
2016-04-11 vscp_getMatrixInfo nw use the pointer supplied by the framework.
2016-04-19 RA4 set to input to prevent collision with VCAP circuits in PIC18F2580. Brown out raised to maximum (3V & 4.6V). Valable input from Anders Forsgren, AJE Electronics AB.
    [main.c]
2020-05-08 Increased forced init time. Fixed init bug
    [accra.h, main.c]
2020-05-14 Fixed problem with init on power up. Fixed seconds counting.
    [main.c]
2020-05-19 Fixed faulty include file
    [main.c]
2022-06-09 Fixed path to schematics
2022-06-09 Added missing file (board layout)
2025-08-18 Converted layout to kicad
    [accra_A.kicad_pcb, accra_A.kicad_sch]

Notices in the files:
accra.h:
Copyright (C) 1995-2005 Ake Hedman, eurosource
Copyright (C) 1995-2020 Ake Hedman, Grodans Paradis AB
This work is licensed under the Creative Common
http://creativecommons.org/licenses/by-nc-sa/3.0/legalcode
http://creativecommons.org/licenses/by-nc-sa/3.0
